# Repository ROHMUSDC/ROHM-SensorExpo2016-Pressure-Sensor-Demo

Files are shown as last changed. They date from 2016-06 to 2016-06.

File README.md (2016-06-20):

# ROHM Balloon Game Demo Public Repository
* Applicable Part Number Used: BM1383AGLV
* Applicable Part Number Demo/Development: SENSORSHLD1-EVK-101
* Description:  This Repo Containg Code, HW design files, and Explaination of how to run the balloon game demo featured at Sensors Expo 2016
* Website link:  TO BE ADDED
* Developer: USDC Applications Engineering Team, ROHM Semiconductor
* Date Started: JUNE 2016
* Related Projects: https://github.com/ROHMUSDC/ROHMSensorPlatformEVK , http://www.rohm.com/web/global/multi-sensor-shield

----
### Repository Contents
* "Documentation" Folder
  * "Sensor Shield General Datasheet" Folder - Contains the General Datasheet for this Shield Board
  * "Sensor Datasheets" Folder - Contains Datasheets for sensors on the Shield Board
* "HW Source Files" Folder 
  * "SENSORSHLD0-EVK-101 HW Design Files" Folder - Contains Schematic, BOM, Layout, Gerber Files for this revision of the Shield Board
  * "SENSORSHLD1-EVK-101 HW Design Files" Folder - Contains Schematic, BOM, Layout, Gerber Files for this revision of the shield Board
* "Platform Code" Folder
  * "Arduino_UNO_FirmwareExample" Folder - Provides documentation and example code for Arduino UNO Platform
  * "LAPIS_SensorPlatform_Firmware" Folder - Provides example code for ROHM's Sensor Platform Kit
  * "MultiTech_Dragonfly_FirmwareExample" Folder - Provides documentation and example code for MultiTech's Dragonfly
  * "Nordic_nRF51-DK_FirmwareExample" Folder - Provides documentation and example code for Nordic nRF51-DK
  * "NXP_LPCXpresso54102_BlinkyExample" Folder - Provides example code for NXP's LPCXpresso54102

----
### Current Supported Platforms
* Arduino UNO, Firmware Example and Documentation (This is our recommended starting point)
* LPCXpresso54102, Firmware Example Only
* Nordic Semiconductor nRF51-DK, Firmware Example and Documentation 
	*  Recommended for BTLE Low Power Sensor Applications
    *  MBED Repository Page: https://developer.mbed.org/teams/ROHMUSDC/code/Nordic_UART_TEMPLATE_ROHM/
* ROHM Sensor Platform Kit: Firmware Example  Only
	*  ROHM Sensor Platform Repository: https://github.com/ROHMUSDC/ROHMSensorPlatformEVK
* MultiTech Dragonfly and MTUDK2, Firmware Example and Documentation
	*  Recommended for Cellular Network Compatibility Applications
    *  MBED Repository Page: https://developer.mbed.org/teams/ROHMUSDC/code/MultiTech_DragonFly_ROHMSensorShield_Sam/

----
### FAQ
* Question:
	* What is the difference between SENSORSHLD0-EVK-101 and SENSORSHLD1-EVK-101?
* Answer:
	* Removed Erroneous Jumpers
	* Removed J5 to J11 and adjusted routing for J1 to J4
	* Added ROHM BM1422GMV Magnetometer, 1.8V level shifter, and 1.8V LDO (for Magnetometer usage)
	* Changed pressure sensor from BM1383GLV to BM1383AGLV.  (No HW change, but new PN has new FW I2C register mapping)
	* PN Change from ML8511 to ML8511A (only chip labelling change)
	* Kionix Corner Accelerometer: one PN, KX123-1050, has been adjusted to the KX124-1050
	
* Question:
	* I see x2 KX122-1037 and x2 KX122-1048 Accelerometers on the board.  What is the difference between these two part numbers?
* Answer: 
	  * The difference between KX122-1037 and KX122-1048 is the I2C register address scheme to control all 4 accelerometers using a single I2C master.  
	  * The KX122-1037 has a 7-bit register address of 0x1E or 0x1F (0x1E if ADDR pin is tied to GND, and 0x1F is ADDR pin is tied to VDD)
	  * The KX122-1048 has a 7-bit register address of 0x1C or 0x1D (0x1C if ADDR pin is tied to GND, and 0x1D is ADDR pin is tied to VDD)
	  * All other accelerometer functionality is the same.  Please see the datasheet for both devices at the following page: http://www.kionix.com/product/KX122-1037

* Question:
	* I've programmed my Arduino Uno board with the sample code provided in this repository.  However, The I2C operation does not seem to work. Do you know what may be the cause?
* Answer:
	* On the Arduino Uno board, please note that the I2C pins connected to the top left header are actually routed to pins A4 and A5 on the bottom right connector.  
	* This conflicts with the UV Sensor ADC output already existing on the board.  
	* Thus, in order to re-route this on our board, we suggest the following rework:
		* To disconnect the nets, remove R27 and R32
		* For UV Sensor Operation, connect the top pad of R31 to the bottom pad of R27
	* Please see the documentation "ROHM_SENSORSHLD1-EVK-101_ArduinoUsageManual_2016-05-31.pdf" or "ROHM_SENSORSHLD1-EVK-101_PlatformGuide_Arduino_2016-05-31.pdf" for additional details of this rework.	

----
### DISCLAIMER
This Technical Data is protected under copyright laws.

ROHM hereby grants you a nonexclusive, nontransferable license to use this Technical Data 
as long as you abide by the terms and conditions of this DISCLAIMER. 

However, you are not authorized to sell, loan, rent, lease, redistribute or license this Technical Data, 
in whole or in part, or in modified form, to anyone.

You may modify this Technical Data to suit your specific applications, 
but the rights to derivative works and said modifications shall belong to ROHM. 

You may make copies of this Technical Data as necessary for internal use only within your company.

ROHM shall not be responsible for ensuring proper application on all computer systems.
This Technical Data is provided AS IS. ROHM makes no guarantees, either implicitly or explicitly, 
regarding its usability, functionality, accuracy, merchantability, or fitness for a specific purpose.

In addition, you shall take full responsibility for the use of any information acquired from this Technical Data. 

ROHM does not assume warranty of any kind arising from the use of this Technical Data. ACCORDINGLY, 
IN NO EVENT SHALL ROHM BE RESPONSIBLE, WHETHER THROUGH CONTRACT OR TORT LIABILITY, 
FOR ANY DAMAGES (INCLUDING BUT NOT LIMITED TO LOST PROFITS OR OTHER INCIDENTAL, CONSEQUENTAL, 
OR PUNITIVE DAMAGES) ARISING OUT OF OR IN CONNECTION WITH THE USE OR APPLICATION OF THIS Technical Data.

Furthermore, this Technical Data is subject to change without notice.

Unless otherwise expressly provided herein, ROHM does not convey any license under patent rights 
or any other intellectual property rights (including those of third parties).

ROHM is not obligated to provide maintenance or support for the Technical Data.

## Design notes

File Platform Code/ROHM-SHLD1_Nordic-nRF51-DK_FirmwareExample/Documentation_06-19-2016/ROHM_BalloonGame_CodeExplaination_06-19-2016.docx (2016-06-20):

# Connecting the ROHM Sensor Shield to the Nordic nRF51-DK

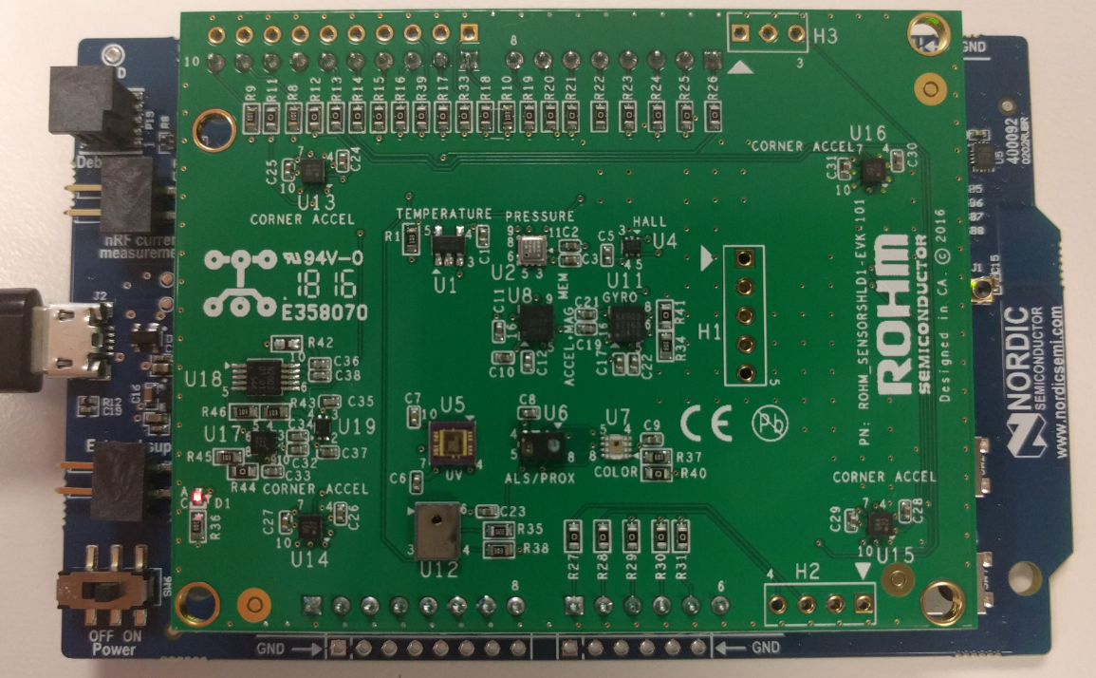
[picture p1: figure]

Above: ROHM SENSORSHLD1-EVK-101 directly connected to the Nordic nRF51-DK Platform

08 June 2016, Revision A

# Copyright and License

[Need to add Nordic References Here]

Please note that all references to ROHM’s Multi-Sensor Shield are also shared under open source guidelines under the GNU General Public License, Version 3. Details can be found at the following link: https://github.com/ROHMUSDC/ROHM_SensorPlatform_Multi-Sensor-Shield.

# Revision History

Date | Description | Revision ID
11 September 2015 | First Draft | A
25 November 2015 | Added Additional Sensor Information | A

# Introduction

The following document was written to provide a brief connection guide and starting point for using ROHM’s Multi-sensor shield with the Nordic nRF51-DK. This guide assumes that the user has basic functional knowledge of both the ROHM Multi-Sensor Shield and the Nordic Platform itself. If this is not correct, please see the following links for other guides and information on these products.

ROHM’s Multi-Sensor Shield GitHub Repository Page: https://github.com/ROHMUSDC/ROHM_SensorPlatform_Multi-Sensor-Shield

Nordic NRF51-DK MBED Platform Page: https://developer.mbed.org/platforms/Nordic-nRF51-DK/

Please note that the Nordic NRF51-DK Platform is a microcontroller platform; thus, this document will explain and show examples of how to connect to and convert values for the ROHM Sensor Kit Sensors. This includes explanations on the following sensors:

- ROHM BDE0600G – Analog Temperature Sensor
- LAPIS ML8511 – Analog UV Sensor
- ROHM BU52011HFV – Hall Switch Sensor
- KIONIX KMX62 – Digital Accelerometer and Magnetometer
- ROHM BM1383AGLV – Digital Barometric Pressure Sensor
- ROHM RPR-0521 – Digital Ambient Light Sensor and Proximity Sensor
- ROHM BH1745 – Digital Color Sensor
- KIONIX KX122 – Digital Accelerometer
- KIONIX KXG03 – Digital Gyroscopic Sensor
- ROHM BM1422 – MI Magnetometer Sensor

# Code Differences between ROHM SHLD0 and SHLD1

- Pressure Sensor is different on this board and uses an updated register map. See the Pressure sensor datasheet for more details (Temperature and pressure output are switched in I2C register map)
- Added section for newly added BM1422 Magnetometer Sensor IC
- Gyro Device I2C address changed due to conflict with other sensors. 7bit address was 0x4F and is not 0x4E (ADDR tied to GND on EVK board)

# Getting Started

1. Initial Setup
  a. ROHM Multi-Sensor Shield Board
    i. For this guide we will connect ROHM’s Multi-Sensor Shield board directly to the Nordic Platform using the standard Arduino Shield Headers
  b. The following are recommended for using the Nordic Platform for this guide
    i. PC
    ii. MBED account for online compiler access
    iii. USB Cable to power and program
    iv. Import the example code from the following repository on the MBED site into your online MBED complier
      1. https://developer.mbed.org/teams/ROHMUSDC/code/Nordic_UART_TEMPLATE_ROHM_SHLD1Update/

# Connecting ROHM Multi-Sensor Shield to the Nordic NRF51-DK Platform

## Hardware Connection for ROHM BDE0600G Temp Sensor to the Nordic Platform

- ROHM BDE0600G – Analog Temperature Sensor

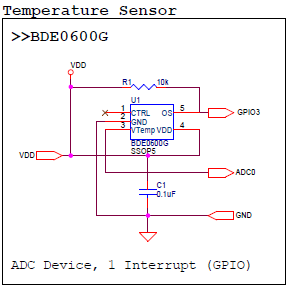
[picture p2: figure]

- As seen in the schematic above, this device connects 4 pins.
  - VDD – Connect to Nordic 3.3V output pin on power connector
  - GND – Connect to Nordic GND pin on the power connector
  - ADC0 – ADC Output for Temperature Readings, Connected to pin P0.03 on Nordic Board
  - GPIO3 – This pin is used to trigger the thermostat output function. This pin is not used in the example application.

## Software Explanation for ROHM BDE0600G Temp Sensor to the Nordic Platform

- Code Segments pertaining to this sensor can be found by defining and seeing code within the “AnalogTemp” #ifDef statements
- Pseudo-Code Explanation
  - Define Relevant Variables
  - Begin Loop()
    1. Read back the Analog Sensor Output from Pin P0.03
      - Note: Default Nordic Reference voltage is 5V; however we are supplying 3.3V to the sensor. Take these values into account when performing your conversions!
    2. Convert value to V, then to Temperature reading
      - Known Values
        - Temperature Sensitivity = -10.68mV/degC
        - Temperature Sensitivity = -0.01068V/degC
        - Temp Known Point = 1.753V @ 30 degC
      - Calculation
        - ADC_Voltage = (sensorValue / 1024) * 2.9V
        - ADC_Voltage = sensorValue * (2.9V/1024)
        - ADC_Voltage = sensorValue * 0.00283
        - Temperature (in deg C) = (ADC_Voltage - 1.753)/(-0.01068) + 30
    3. Format Serial Output and Return Information

## Hardware Connection for LAPIS ML8511 UV Sensor to the Nordic Platform

- LAPIS ML8511 – Analog UV Sensor

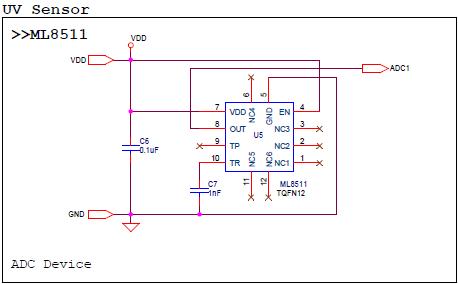
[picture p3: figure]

- As seen in the schematic above, this device connects 3 pins.
  - VDD – Connect to Nordic 3.3V output pin on power connector
  - GND – Connect to Nordic GND pin on the power connector
  - ADC1 – ADC Output for UV Sensor Output, Connected to pin P0.05 on Nordic Board

Software Explanation for LAPIS ML8511 UV Sensor to the Arduino Uno

- Code Segments pertaining to this sensor can be found by defining and seeing code within the “AnalogUV” #ifDef statements
- Pseudo-Code Explanation
  - Define Relevant Variables
  - Begin Loop()
    4. Read back the Analog Sensor Output from Pin P0.05
      - Note: Default Nordic Reference voltage is 5V; however we are supplying 3.3V to the sensor. Take these values into account when performing your conversions!
    5. Convert value to V, then to UV Intensity
      - Known Values
        - UV Sensitivity = 0.129 V/(mW/cm²)
        - Temp Known Point = 2.2V @ 10mW/cm²
      - Calculation
        - ADC_Voltage = (sensorValue / 1024) * 2.9V
        - ADC_Voltage = sensorValue * (2.9V/1024)
        - ADC_Voltage = sensorValue * 0.0029
        - UV Intensity (in mW/cm²)= (ADC_Voltage - 2.2)/(0.129) + 10
    6. Format Serial Output and Return Information

## Hardware Connection for ROHM BU52014 Hall Sensor to the Nordic Platform

- ROHM BU52011HFV – Hall Switch Sensor

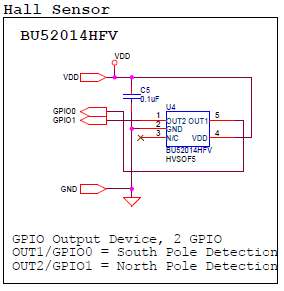
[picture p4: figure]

- As seen in the schematic above, this device connects 4 pins.
  - VDD – Connect to Nordic 3.3V output pin on power connector
  - GND – Connect to Nordic GND pin on the power connector
  - GPIO0, GPIO1 – Indicates Hall Switch Output
    - GPIO0: Indicates South Pole Detection
    - GPIO1: Indicates North Pole Detection

## Software Explanation for ROHM BU52014 Hall Sensor to the Nordic Platform

- Code Segments pertaining to this sensor can be found by defining and seeing code within the “HallSensor” #ifDef statements
- Pseudo-Code Explanation
  - Define Relevant Variables
  - Begin setup()
    7. Setup Nordic Pins P0.14 and P0.15 and Input pins
  - Begin loop()
    8. Perform digital reads on pins P0.14 and P0.15
      - Output will be either 1 or 0 and will indicate presence of north or south magnetic fields
    9. Format Serial Output and Return Information

## Hardware Connection for Kionix KMX62 Accel+Mag Sensor to the Nordic Platform

- Kionix KMX62 – Digital Accelerometer and Magnetometer

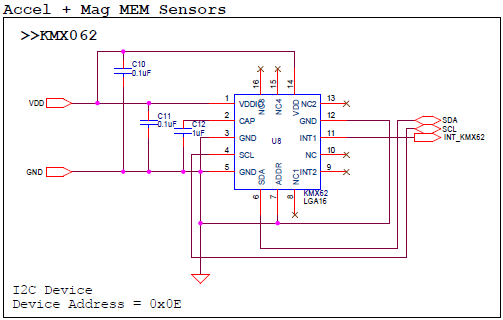
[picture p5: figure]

- As seen in the schematic above, this device connects 6 pins.
  - VDD – Connect to Nordic 3.3V output pin on power connector
  - GND – Connect to Nordic GND pin on the power connector
  - SDA/SCL – I2C Connection, connected to pin P0.30 and P0.07
  - INT_KMX62 - This pin is used monitor the interrupt pins on the KMX61. This pin is not used in the example application.

## Software Explanation for Kionix KMX62 Accel+Mag Sensor to the Nordic Platform

- Code Segments pertaining to this sensor can be found by defining and seeing code within the “KMX62” #ifDef statements
- Pseudo-Code Explanation
  - Define Relevant Variables
  - Begin Main()
    10. Set Baud Rate for Serial Output via Nordic BT Protocols
    11. Initialize Board Level LEDs
    12. Setup Interrupt Callback for “Periodic Callback”
    13. Setup PB for SW4
    14. Configure the Accel/Mag Sensor once by performing the following writes
      - 1. CNTL2 Register (0x3A), write 0x5F (4g Sensor Resolution, Max RES, Enable Temp/Mag/Accel)
        - Note: Please see the KMX62 Datasheet for additional information on these registers
  - Begin loop()
    15. Read back the Accelerometer output by reading 6 Bytes starting from address 0x0A. [0][1]...[5]
    16. Format Each of the X, Y, and Z axis acceleration
      - Note: to save some time with conversions, please note that these outputs are meant to be unsigned 14bit values. Thus, to make it easier to convert we recommend the following…
        - Xout = (float)(([1]<<8) | ([0]))/4
        - Yout = (float)(([3]<<8) | ([2]))/4
        - Zout = (float)(([5]<<8) | ([4]]))/4
    17. Convert Returned Value to g
      - Axis_ValueInG = MEMS_Accel_axis / 2048
    18. Read back the Magnetometer output by reading 6 Bytes starting from address 0x10. [0][1]...[5]
    19. Format Each of the X, Y, and Z axis mag data
      - Note: to save some time with conversions, please note that these outputs are meant to be unsigned 14bit values. Thus, to make it easier to convert we recommend the following…
        - Xout = (float)(([1]<<8) | ([0]))/4
        - Yout = (float)(([3]<<8) | ([2]))/4
        - Zout = (float)(([5]<<8) | ([4]]))/4
    20. Convert Returned Value to uT
      - Axis_ValueInuT = MEMS_Mag_axis * 0.146
    21. Format Serial Output and Return Information

## Hardware Connection for ROHM BM1383GLV Barometric Pressure Sensor to the Nordic Platform

- ROHM BM1383GLV Barometric Pressure Sensor

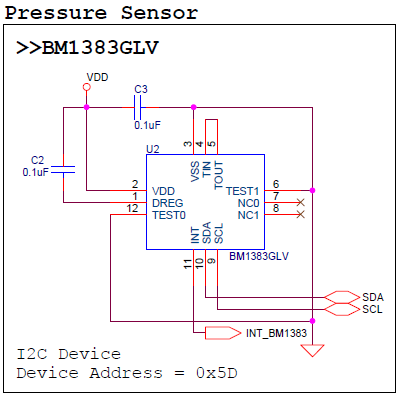
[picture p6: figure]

- As seen in the schematic above, this device connects 6 pins.
  - VDD – Connect to Nordic 3.3V output pin on power connector
  - GND – Connect to Nordic GND pin on the power connector
  - SDA/SCL – I2C Connection, connected to pin P0.30 and P0.07
  - INT_BM1383 - This pin is used monitor the interrupt pins on the BM1383. This pin is not used in the example application.

## Software Explanation for ROHM BM1383GLV Barometric Pressure Sensor to the Nordic Platform

- Code Segments pertaining to this sensor can be found by defining and seeing code within the “Pressure” #ifDef statements
- Pseudo-Code Explanation
  - Define Relevant Variables
  - Begin Main()
    22. Set Baud Rate for Serial Output via Nordic BT Protocols
    23. Initialize Board Level LEDs
    24. Setup Interrupt Callback for “Periodic Callback”
    25. Configure the Pressure Sensor once by performing the following writes:
      - 1. PWR_DOWN Register (0x12), write (0x01)
      - 2. SLEEP Register (0x13), write (0x01)
      - 3. Mode Control Register (0x14), write (0xC4)
      - Note: Please see the BM1383 datasheet for additional information on these registers
  - Begin loop()
    26. Read back the pressure and temperature output by reading 5 Bytes starting from address 0x1A. [0][1]...[4]
    27. Format raw temperature and pressure
      - Raw ADC Pressure (Integer Portion) = ([0]<<3) | ([1]>>5)
      - Raw ADC Pressure (Decimal Portion) = (([1] & 0x1f) << 6 | (([2] >> 2)));
      - Raw ADC Temp = ([3]<<8) | ([4])
    28. Convert Returned Raw Value to Real Values
      - Temp in C = Raw ADC Temp / 32
      - Pressure in hPa =
        - (Raw ADC Pressure(int)) + (Raw ADC Pressure(dec)*2⁻¹¹)
    29. Format Serial Output and Return Information

## Hardware Connection for ROHM RPR-0521 3-in-1 Ambient Light Sensor, Proximity Sensor, and IR LED Combo Package for the Nordic Platform

- ROHM RPR-0521 ALS/PROX Sensor

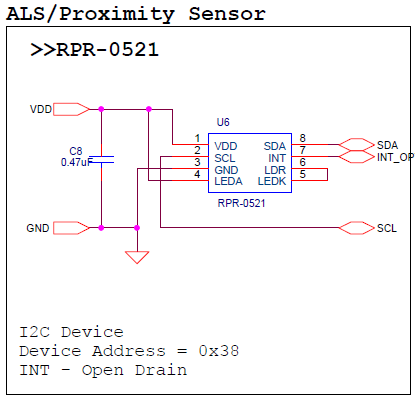
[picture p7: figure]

- As seen in the schematic above, this device connects 6 pins.
  - VDD – Connect to Nordic 3.3V output pin on power connector
  - GND – Connect to Nordic GND pin on the power connector
  - SDA/SCL – I2C Connection, connected to pin P0.30 and P0.07
  - INT_Optical - This pin is used monitor the interrupt pins on the RPR-0521. This pin is not used in the example application.

## Software Explanation for ROHM RPR-0521 3-in-1 Ambient Light Sensor, Proximity Sensor, and IR LED Combo Package to the Nordic Platform

- Code Segments pertaining to this sensor can be found by defining and seeing code within the “RPR0521” #ifDef statements
- Pseudo-Code Explanation
  - Define Relevant Variables
  - Begin Main()
    30. Set Baud Rate for Serial Output via Nordic BT Protocols
    31. Initialize Board Level LEDs
    32. Setup Interrupt Callback for “Periodic Callback”
    33. Configure the Ambient Light Sensor and Proximity Sensor once by performing the following writes:
      - 1. Mode Control Register (0x41), write (0xC6)
      - 2. ALS_PS_Control Register (0x42), write (0x03)
      - 3. Persist Register (0x43), write (0x20)
      - Note: Please see the RPR-0521 datasheet for additional information on these registers
  - Begin loop()
    34. Read back the ALS output by reading 6 Bytes starting from address 0x44. [0][1]...[5]
    35. Format Raw ambient light and proximity
      - RAW PROX ADC = ([1]<<8) | ([0])
      - RAW ALS DATA0 = ([3]<<8) | ([2])
      - RAW ALS DATA1 = ([5]<<8) | ([4])
    36. Convert Raw Returned Value to Real Values
      - ALS can be returned by using the following code block to return ALS value in lx (RPR0521_ALS_OUT)
    37. Format Serial Output and Return Information

## Hardware Connection for ROHM BH1745NUC Color Sensor for the Nordic Platform

- ROHM BH1745NUC Color Sensor

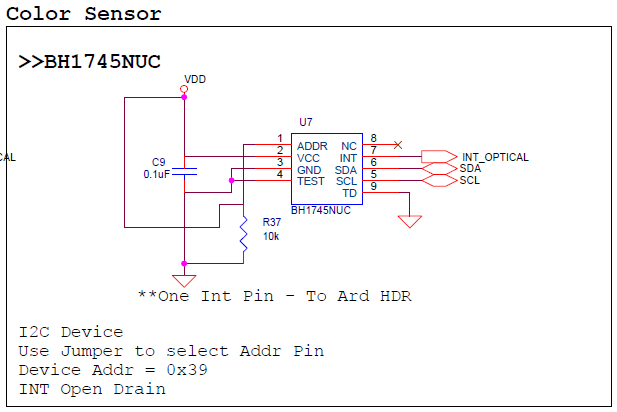
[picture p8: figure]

- As seen in the schematic above, this device connects 6 pins.
  - VDD – Connect to Nordic 3.3V output pin on power connector
  - GND – Connect to Nordic GND pin on the power connector
  - SDA/SCL – I2C Connection, connected to pin P0.30 and P0.07
  - INT_Optical - This pin is used monitor the interrupt pins on the RPR-0521. This pin is not used in the example application.

## Software Explanation for ROHM BH1745NUC Color Sensor to the Nordic Platform

- Code Segments pertaining to this sensor can be found by defining and seeing code within the “Color” #ifDef statements
- Pseudo-Code Explanation
  - Define Relevant Variables
  - Begin Main()
    38. Set Baud Rate for Serial Output via Nordic BT Protocols
    39. Initialize Board Level LEDs
    40. Setup Interrupt Callback for “Periodic Callback”
    41. Configure the Color Sensor once by performing the following writes:
      - 1. Persistence Register (0x61), write (0x03)
      - 2. Mode Control 1 Register (0x41), write (0x00)
      - 3. Mode Control 2 Register (0x42), write (0x92)
      - 4. Mode Control 3 Register (0x43), write (0x02)
      - Note: Please see the color sensor datasheet for additional information on these registers
  - Begin loop()
    42. Read back the color output by reading 6 Bytes starting from address 0x50. [0][1]...[5]
    43. Format Raw color
      - RED ADC = ([1]<<8) | ([0])
      - GREEN ADC = ([3]<<8) | ([2])
      - BLUE ADC = ([5]<<8) | ([4])
    44. Convert Raw Returned Value to Real Values
      - Coming Soon!
    45. Format Serial Output and Return Information

## Hardware Connection for Kionix KX122 Accelerometer Sensor for the Nordic Platform

- Kionix KX122 Accelerometer Sensor

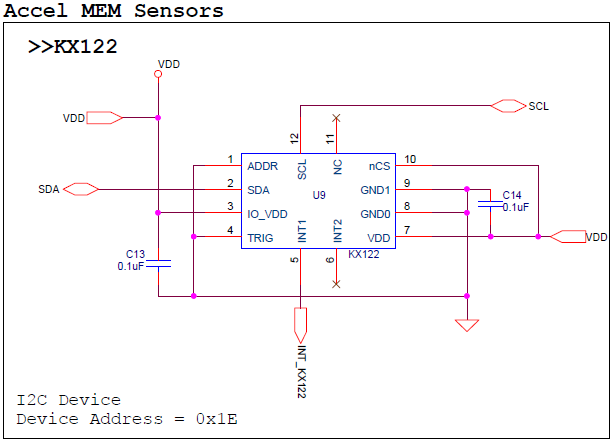
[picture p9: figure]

- As seen in the schematic above, this device connects 6 pins.
  - VDD – Connect to Nordic 3.3V output pin on power connector
  - GND – Connect to Nordic GND pin on the power connector
  - SDA/SCL – I2C Connection, connected to pin P0.30 and P0.07
  - INT_KX122 - This pin is used monitor the interrupt pins on the KX122. This pin is not used in the example application.

## Software Explanation for Kionix KX122 Accelerometer Sensor to the Nordic Platform

- Code Segments pertaining to this sensor can be found by defining and seeing code within the “KX122” #ifDef statements
- Pseudo-Code Explanation
  - Define Relevant Variables
  - Begin Main()
    46. Set Baud Rate for Serial Output via Nordic BT Protocols
    47. Initialize Board Level LEDs
    48. Setup Interrupt Callback for “Periodic Callback”
    49. Configure the Accelerometer Sensor once by performing the following writes:
      - 1. CNTL1 Register (0x18), write (0x41)
      - 2. ODCNTL Register (0x1B), write (0x02)
      - 3. CNTL3 Register (0x1A), write (0xD8)
      - 4. TILT_TIMER Register (0x22), write (0x01)
      - 5. CNTL1 Register (0x18), write (0xC1) (Enable bit to ON)
      - Note: Please see the KX122 datasheet for additional information on these registers
  - Begin loop()
    50. Read back the Accelerometer output by reading 6 Bytes starting from address 0x06. [0][1]...[5]
    51. Format Raw accelerometer
      - ACCEL X Axis Raw = ([1]<<8) | ([0])
      - ACCEL Y Axis Raw = ([3]<<8) | ([2])
      - ACCEL Z Axis Raw = ([5]<<8) | ([4])
    52. Convert Raw Returned Value to g
      - ACCEL X in g = ACCEL X Axis Raw / 16384
      - ACCEL X in g = ACCEL Y Axis Raw / 16384
      - ACCEL X in g = ACCEL Z Axis Raw / 16384
    53. Format Serial Output and Return Information

## Hardware Connection for Kionix KXG03 Gyroscopic Sensor for the Nordic Platform

- Kionix KXG03 Gyroscopic Sensor

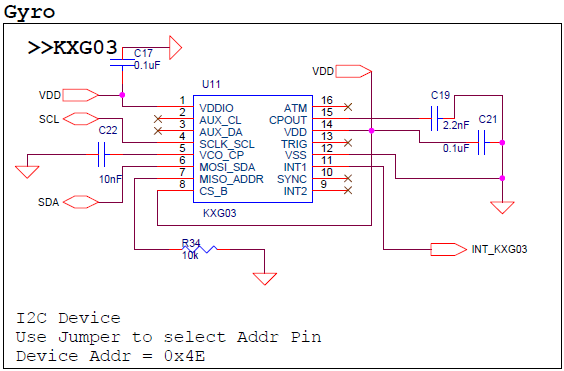
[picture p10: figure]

- As seen in the schematic above, this device connects 6 pins.
  - VDD – Connect to Nordic 3.3V output pin on power connector
  - GND – Connect to Nordic GND pin on the power connector
  - SDA/SCL – I2C Connection, connected to pin P0.30 and P0.07
  - INT_KXG03 - This pin is used monitor the interrupt pins on the KXG03. This pin is not used in the example application.

## Software Explanation for Kionix KXG03 Gyroscopic Sensor to the Nordic Platform

- Code Segments pertaining to this sensor can be found by defining and seeing code within the “KXG03” #ifDef statements
- Pseudo-Code Explanation
  - Define Relevant Variables
  - Begin Main()
    54. Set Baud Rate for Serial Output via Nordic BT Protocols
    55. Initialize Board Level LEDs
    56. Setup Interrupt Callback for “Periodic Callback”
    57. Configure the Gyroscopic Sensor once by performing the following writes:
      - STDBY Register (0x43), write 0x00.
      - Note: Please see the KXG03 datasheet for additional information on these registers
  - Begin loop()
    58. Read back the Gyroscopic output by reading 6 Bytes starting from address [0x02]. [0][1]...[5]
    59. Format Raw Gyro data
      - Gyro_X_RawOUT = ([1]<<8) | ([0])
      - Gyro_Y_RawOUT = ([3]<<8) | ([2])
      - Gyro_Z_RawOUT = ([5]<<8) | ([4])
    60. Cancel for offset value
- Measure RawOUT data 10 times in order to proofread offset value.
- Calculate average offset value. This data is defined as proofread data.
- Subtract proofread data from each RawOUT data.
    61. Convert Raw Returned Value to deg/sec
      - Gyro_ X = (float)KXG03_Gyro_X_RawOUT2 * 0.007813 + 0.000004
      - Gyro_ Y = (float)KXG03_Gyro_Y_RawOUT2 * 0.007813 + 0.000004
      - Gyro_Z = (float)KXG03_Gyro_Z_RawOUT2 * 0.007813 + 0.000004
    62. Format Serial Output and Return Information

## Hardware Connection for ROHM BM1422 Magnetometer Sensor for the Arduino Uno

- ROHM BM1422Magnetometer Sensor

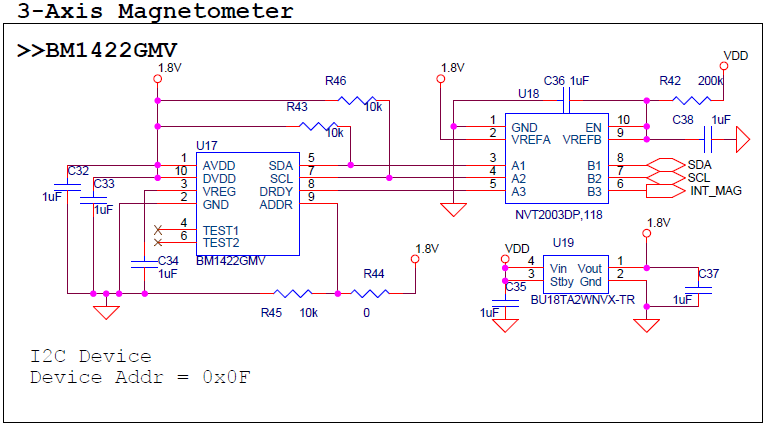
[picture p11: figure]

- As seen in the schematic above, this device is slightly more complicated than the other devices on this shield.
  - Part Explanation:
    - U17 = BM1422GMV Magnetometer
      - 1.8V max input voltage… therefore, we can’t use the 3.3V rail native to the system. U18 and U19 are added to protect the magnetometer from the 3.3V system voltage.
    - U18 = NVT2003DP Level Shifter for I2C and Interrupt lines
      - Used to reduce I2C interface and interrupt pin connection’s 3.3V signals from the Arduino board to 1.8V to the sensor.
    - U19 = BU18TA2WNVX LDO Regulator
      - Used to source power to the magnetometer and the 1.8V logic level side of the level shifter U18
- When looking at this system together, we can see than ultimately, there are 5 connections
  - VDD – Connect to Arduino 3.3V output pin on power connector
  - GND – Connect to Arduino GND pin on the power connector
  - SDA/SCL – I2C Connection, connected to A4 and A5
  - INT_MAG - This pin is used monitor the interrupt pins on the BM1422GMV. This pin is not used in the example application.

## Software Explanation for ROHM BM1422 Magnetometer Sensor to the Arduino Uno

- Code Segments pertaining to this sensor can be found by defining and seeing code within the “Magnetometer” #ifDef statements
- Pseudo-Code Explanation
  - Define Relevant Variables
  - Begin Main()
    63. Set Baud Rate for Serial Output via Nordic BT Protocols
    64. Initialize Board Level LEDs
    65. Setup Interrupt Callback for “Periodic Callback”
    66. Configure the Magnetometer Sensor once by performing the following writes:
      - 1. CNTL1 Register (0x1B), write 0xC0
      - 2. CNTL4 Register (0x5C), write 0x00
      - 3. CNTL4 Register (0x5D), write 0x00
      - 4. CNTL3 Register (0x1D), write 0x40
      - Note: Please see the BM1422GMV datasheet for additional information on these registers
  - Begin loop()
    67. Read back the Magnetometer Sensor output by reading 6 Bytes starting from address 0x10. [0][1]...[5]
    68. Format Raw Magnetometer data
      - Mag_X_RawOUT = ([1]<<8) | ([0])
      - Mag_Y_RawOUT = ([3]<<8) | ([2])
      - Mag_Z_RawOUT = ([5]<<8) | ([4])
    69. Format Serial Output and Return Information

Connecting ROHM’s Sensor Shield to Nordic nRF51-DK SENSORSHLD1-EVK-101 08 June, 2016 – Revision A

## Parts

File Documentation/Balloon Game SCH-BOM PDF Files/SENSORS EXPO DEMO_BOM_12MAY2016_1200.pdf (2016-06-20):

Sensors Expo Demo
Revision: 0.01

Bill Of Materials

Item | Quantity | Reference | Part | PCB Footprint | DESCRIPTION | MFG1 | MFG1_PART# | DISTR1 | DISTR1_PART# | Note
1 | 1 | B2 | Li-Ion | 100mil_VIA-2 | | | | | | DNP
2 | 1 | C97 | 1.0pF | C0402 | CAP CER 1PF 50V NP0 0402 | Samsung | CL05C010CB5NNNC | Digi-Key | 1276-1595-1-ND
3 | 1 | C99 | 1.2pF | C0402 | CAP CER 1.2PF 50V .25PF 0402 | Murata | GRM1555C1H1R2CA01D | Digi-Key | 490-5927-1-ND
4 | 1 | C98 | 1.5pF | C0402 | CAP CER 1.5PF 50V NP0 0402 | Murata | GRM1555C1H1R5CA01D | Digi-Key | 490-5891-1-ND
5 | 1 | C96 | 3.9pF | C0402 | CAP CER 3.9PF 50V NP0 0402 | Murata | GRM1555C1H3R9CA01D | Digi-Key | 490-5940-1-ND
6 | 4 | C86,C87,C90,C9112pF | | C0402 | CAP CER 12PF 50V NP0 0402 | Samsung | CL05C120JB5NNNC | Digi-Key | 1276-1178-1-ND
7 | 2 | C102,C119 | 120pF | C0402 | CAP CER 120PF 10V X7R 01005 | Murata | GRM022R71A121KA01L | Digi-Key | 490-8617-1-ND
8 | 1 | C93 | 1.0nF | C0402 | CAP CER 1000PF 50V X7R 0402 | Murata | GRM155R71H102KA01D | Digi-Key | 490-1303-1-ND
9 | 2 | C94,C127 | 2.2nF | C0402 | CAP CER 2200PF 50V 10% X5R 0402 | Murata | GRM155R61H222KA01D | Digi-Key | 490-8257-1-ND
10 | 2 | C105,C121 | 2200pF | C0402 | CAP CER 2200PF 16V 10% X5R 0402 | Murata | GRM155R61C222KA01D | Digi-Key | 490-6311-1-ND
11 | 1 | C129 | 10nF | C0402 | CAP CER 10000PF 16V 10% X5R 0402 | Murata | GRM155R61C103KA01D | Digi-Key | 490-6309-1-ND
12 | 1 | C95 | 47nF | C0402 | CAP CER 0.047UF 16V X7R 0402 | Kemet | C0402C473K4RACTU | Digi-Key | 399-3519-1-ND
13 | 12 | C88,C89,C92,C103,C104,C108,C109,C111,C128,C130,C131,C132 0.1uF | | C0402 | CAP CER 0.1UF 16V X5R 0402 | Murata | GRM155R61C104KA88D | Digi-Key | 490-5415-1-ND
14 | 1 | C125 | 0.33uF | C0402 | CAP CER 0.33UF 10V X5R 0402 | Murata | GRM155R61A334KE15D | Digi-Key | 490-3263-1-ND
15 | 11 | C106,C110,C112,C113,C114,C115,C117,C120,C124,C126,C133 1uF | | C0402 | CAP CER 1UF 16V X5R 0402 | Murata | GRM155R61C105KE01D | Digi-Key | 490-10453-1-ND
16 | 1 | C122 | 2.2uF | C0402 | CAP CER 2.2UF 16V X5R 0402 | Murata | GRM155R61C225KE11D | Digi-Key | 490-10695-1-ND
17 | 3 | C82,C83,C85 | 4.7uF | C0402 | CAP CER 4.7UF 6.3V X5R 0402 | Murata | GRM155R60J475ME47D | Digi-Key | 490-5915-1-ND
18 | 4 | C101,C107,C116,C118 10uF | | C1206 | CAP CER 10UF 10V X5R 1206 | Murata | GRM31CR61A106KA01L | Digi-Key | 490-1820-1-ND
19 | 1 | C84 | 100uF | C1206 | CAP CER 100UF 6.3V X5R 1206 | Taiyo Yuden | JMK316ABJ107ML-T | Digi-Key | 587-3395-1-ND
20 | 1 | C100 | DNP | C0402 | | | | | | DNP
21 | 1 | C123 | DNP | C0402 | CAP CER 2.2UF 16V X5R 0402 | Murata | GRM155R61C225KE11D | Digi-Key | 490-10695-1-ND | DNP
22 | 2 | D3,D4 | LED | D0402 | LED GREEN CLEAR 0402 SMD | Rohm | SML-P11MTT86 | Digi-Key | 511-1652-2-ND
23 | 1 | J10 | 1x8 HEADER | HDR_1X8_100 | CONN HEADER 8 POS 2.54 | Würth Elektronik | 61300811121 | Digi-Key | 732-5321-ND
24 | 1 | L12 | 3.3nH | L0402 | FIXED IND 3.3NH 550MA 160 MOHM | Taiyo Yuden | HK10053N3S-T | Digi-Key | 587-1507-1-ND
25 | 1 | L10 | 4.7nH | L0402 | FIXED IND 4.7NH 300MA 240 MOHM | Johanson | L-07C4N7SV6T | Digi-Key | 712-1417-1-ND
26 | 1 | L9 | 15nH | L0603 | FIXED IND 15NH 300MA 450 MOHM | Johanson | L-14C15NJV4T | Digi-Key | 712-1436-1-ND
27 | 1 | L11 | 27nH | L0402 | FIXED IND 27NH 300MA 460 MOHM | Murata | LQG15HS27NJ02D | Digi-Key | 490-2628-1-ND
28 | 1 | L13 | 4.7uH | INDM3838X165 | FIXED IND 4.7UH 1.2A 105 MOHM | Würth Elektronik | 744031004 | Digi-Key | 732-1008-1-ND
29 | 1 | L14 | 4.7uH | INDM3735X180 | Ind Power Shielded 4.7uH 20% 100KHz Ferrite 2A T/R | Murata | 1231AS-H-4R7M=P3 | Mouser | 81-1231AS-H-4R7MP3
30 | 1 | L8 | 10uH | L0805 | FIXED IND 10UH 150MA 360 MOHM | Taiyo Yuden | LBR2012T100K | Digi-Key | 587-2045-1-ND
31 | 2 | TEST1_N,P23 | TP_TH_63MIL_RED | TP_TH | TEST POINT PC MULTI PURPOSE RED | Keystone Electronics | 5010 | DIGIKEY | 5010K-ND
32 | 3 | Q4,Q5,Q6 | RE1C002UNTCL | EMT3 | MOSFET N-CH 20V 0.2A EMT3 | Rohm | RE1C002UNTCL | Digi-Key | RE1C002UNTCLCT-ND
33 | 8 | Q7,Q8,Q9,Q10,Q11,Q12,Q13,Q14 EM6K1T2R | | ROHM_EM6K1_SOT-416 | MOSFET 2N-CH 30V .1A EMT6 | Rohm | EM6K1T2R | Digi-Key | EM6K1T2RCT-ND
34 | 4 | R77,R89,R143,R152 0 | | R0402 | RES SMD 0.0OHM JUMPER 1/16W 0402 | Rohm | MCR01MRTJ000 | Digi-Key | RHM0.0CECT-ND
35 | 15 | R100,R103,R106,R109,R112,R115,R118,R121,R124,R127,R130,R133,R136,R139,R142 22 | | R0402 | RES SMD 22 OHM 5% 1/16W 0402 | Rohm | MCR01MRTJ220 | Digi-Key | RHM22CECT-ND
36 | 15 | R99,R102,R105,R108,R111,R114,R117,R120,R123,R126,R129,R132,R135,R138,R141 36 | | R0402 | RES SMD 36 OHM 5% 1/16W 0402 | Rohm | MCR01MRTJ360 | Digi-Key | RHM36CECT-ND
37 | 2 | R72,R74 | 43 | R0402 | RES SMD 43 OHM 5% 1/16W 0402 | Rohm | MCR01MRTJ430 | Digi-Key | RHM43CECT-ND
38 | 1 | R73 | 56 | R0402 | RES SMD 56 OHM 1% 1/16W 0402 | Rohm | TRR01MZPF56R0 | Digi-Key | RHM56BHCT-ND
39 | 15 | R98,R101,R104,R107,R110,R113,R116,R119,R122,R125,R128,R131,R134,R137,R140 180 | | R0402 | RES SMD 180 OHM 5% 1/16W 0402 | Rohm | MCR01MRTJ181 | Digi-Key | RHM180CECT-ND
40 | 2 | R91,R92 | 200 | R0402 | RES SMD 200 OHM 5% 1/16W 0402 | Rohm | MCR01MRTJ201 | Digi-Key | RHM200CEDKR-ND
41 | 1 | R145 | 430 | R0402 | RES SMD 430 OHM 5% 1/16W 0402 | Rohm | MCR01MRTJ431 | Digi-Key | RHM430CECT-ND
42 | 1 | R146 | 510 | R0402 | RES SMD 510 OHM 5% 1/16W 0402 | Rohm | MCR01MRTJ511 | Digi-Key | RHM510CECT-ND
43 | 1 | R149 | 1k | R0402 | RES SMD 1K OHM 5% 1/16W 0402 | Rohm | MCR01MRTJ102 | Digi-Key | RHM1.0KCECT-ND
44 | 1 | R90 | 2k | R0402 | RES SMD 2K OHM 1% 1/16W 0402 | Rohm | MCR01MRTF2001 | Digi-Key | RHM2KCDCT-ND
45 | 4 | R153,R154,R155,R156 2.2k | | R0402 | RES SMD 2.2K OHM 5% 1/16W 0402 | Rohm | MCR01MRTJ222 | Digi-Key | RHM2.2KCECT-ND
46 | 4 | R79,R87,R148,R150 4.7k | | R0402 | RES SMD 4.7K OHM 5% 1/16W 0402 | Rohm | MCR01MRTJ472 | Digi-Key | RHM4.7KCECT-ND
47 | 15 | R75,R76,R80,R81,R82,R83,R84,R85,R86,R93,R94,R95,R96,R97,R151 10k | | R0402 | RES SMD 10K OHM 5% 1/16W 0402 | Rohm | MCR01MRTJ103 | Digi-Key | RHM10KCEDKR-ND
48 | 2 | R88,R144 | 39k | R0402 | RES SMD 39K OHM 5% 1/16W 0402 | Rohm | MCR01MRTJ393 | Digi-Key | RHM39KCECT-ND
49 | 2 | R70,R71 | 51k | R0402 | RES SMD 51K OHM 1% 1/16W 0402 | Rohm | MCR01MRTF5102 | Digi-Key | RHM51KCDCT-ND
50 | 2 | R78,R147 | 56k | R0402 | RES SMD 56K OHM 5% 1/16W 0402 | Rohm | MCR01MRTJ563 | Digi-Key | RHM56KCECT-ND
51 | 22 | UART_TX1,UART_RX1,TP_SDA1,TP_SCL1,SPI_SCLK1,SPI_RST1,SPI_MOSI1,SPI_MISO1,SPI_CS1,TP20,TP21,TP22,TP23,TP24,TP25,TP26,TP27,TP28,TP29,TP30,TP31,TP32 T POINT R | TP_R | DNP. Not component
52 | 1 | SW1 | EVP-BB2A1B000 | SW_PANASONIC_EVPBB_53H | SWITCH TACTILE SPST-NO 0.02A 15V | Panasonic | EVP-BB2A1B000 | Digi-Key | P17066CT-ND
53 | 1 | U23 | USBmicroB | FCI_10118194-0001LF | CONN USB MICRO B RECPT SMT R/A | FCI | 10118194-0001LF | Digi-Key | 609-4618-1-ND
54 | 1 | U24 | nRF51422 | 48-VFQFN | IC SOC 2.4GHZ 256K FLASH 48QFN | Nordic Semiconductor | NRF51422-QFAA-R7 | Digi-Key | 1490-1030-1-ND
55 | 1 | U25 | ANT2012LL13R2400A | YAGEO_ANT2012 | PIFA CHIP ANTENNA 2.4GHZ | Yageo | ANT2012LL13R2400A | Digi-Key | 311-1534-1-ND
56 | 1 | U26 | SMLVN6RGB | ROHM_SMLVN6RGB1W1 | LED RGB DIFFUSED 6SMD | Rohm | SMLVN6RGB1W1 | Digi-Key | 846-1187-1-ND
57 | 2 | U27,U50 | BD8306MUV | VQFN016V3030 | IC REG BUCK BOOST ADJ 2A 16VQFN | Rohm | BD8306MUV-E2 | Digi-Key | BD8306MUV-E2CT-ND
58 | 2 | U28,U29 | BH1745 | WSON008X2120 | IC COLOR SENSOR DGTL 8WSON | Rohm | BH1745NUC-E2 | Digi-Key | BH1745NUC-E2CT-ND
59 | 1 | U30 | Left Servo | 100mil_Via3 | Custom Part DO NOT POPULATE | | | | | DNP
60 | 1 | U31 | Right Servo | 100mil_Via3 | Custom Part DO NOT POPULATE | | | | | DNP
61 | 1 | U32 | STBC08 | DFN6 | IC BATT CHRGR LI-ION 800MA DFN6 | STMicroelectronics | STBC08PMR | Digi-Key | 497-5808-1-ND
62 | 1 | U33 | BM1383 | CLGA12V025M | Pressure Sensor IC | Rohm | BM1383GLV | TBD | TBD
63 | 1 | U34 | KX122 | LGA12R50P_200X200X90 | ACCELEROMETER TRI-AXIS 12LGA | Kionix | KX122-1037 | Digi-Key | 1191-1041-1-ND
64 | 16 | U35,U36,U37,U38,U39,U40,U41,U42,U43,U44,U45,U46,U47,U48,U49,U51 SMLP34RGB2W | | ROHM_SMLP34 | LED RGB DIFFUSED 0404 SMD | Rohm | SMLP34RGB2W3 | Digi-Key | SMLP34RGB2W3CT-ND
65 | 1 | U52 | ML620Q504H | TQFP50P900X900X120-48 | IC MCU 16BIT 64KB FLASH 48TQFP | Rohm | ML620Q504H-NNNTBWABL | Digi-Key | ML620Q504H-NNNTBWABLCT-ND
66 | 1 | U53 | KXG03 | LGA16R50P_300X300X90 | TRI-AXIS GYROSCOPE/TRI-AXIS ACC | Kionix | KXG03-1034-FR | Digi-Key | 1191-1043-1-ND
67 | 1 | U54 | KX022 | LGA12S50P_200X200X90 | ACCELEROMETER TRI-AXIS 12LGA | Kionix | KX022-1020-FR | Digi-Key | 1191-1038-1-ND
68 | 1 | Y4 | 16MHz | NDK_NX2520SA | CRYSTAL 16.0000MHZ 8PF SMD | NDK | NX2520SA-16MHZ-STD-CSW-5 | Digi-Key | 644-1169-1-ND
69 | 1 | Y5 | 32.768kHz | EPSON_FC-135R | CRYSTAL 32.7680KHZ 6.0PF SMT | Epson | FC-135R 32.7680KA-E3 | Digi-Key | SER4074CT-ND
70 | 2 | J11,J13 | HDR_1X2_2P54MM | HDR_1X2_2P54MM | DNP. Not component
71 | 46 | TP48,TP49,TP50,TP51,TP52,TP53,TP54,TP55,TP56,TP57,TP58,TP59,TP60,TP61,TP62,TP63,TP64,TP65,TP66,TP67,TP68,TP69,TP70,TP71,TP72,TP73,TP74,TP75,TP76,TP77,TP78,TP79,TP80,TP81,TP82,TP83,TP84,TP85,TP86,TP87,TP88,TP89,TP90,TP91,TP92,TP93 TP_300X150 | TP_300X150 | DNP. Not component

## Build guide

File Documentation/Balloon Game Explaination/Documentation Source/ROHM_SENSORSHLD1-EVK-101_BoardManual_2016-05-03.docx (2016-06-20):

# Product Overview: SENSORSHLD1-EVK-101

# ROHM Sensor Shield

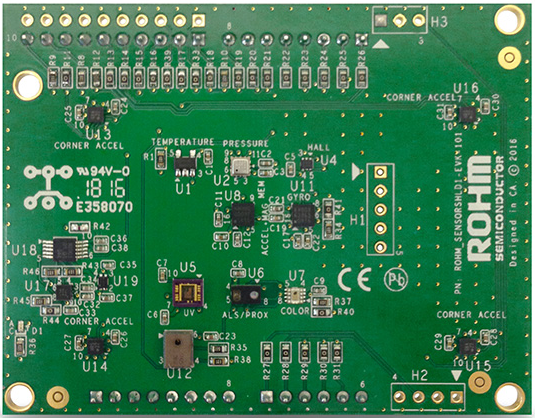
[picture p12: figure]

Above: Top view of ROHM SENSORSHLD1-EVK-101

03 May 2016, Revision A

# Introduction

The following document was written to provide a brief connection guide and general information about ROHM’s SENSORSHLD1-EVK-101. Supplementary information including application examples and HW design files for this board can be found at the following repository link.

ROHM’s Multi-Sensor Shield GitHub Repository Page: https://github.com/ROHMUSDC/ROHM_SensorPlatform_Multi-Sensor-Shield

ROHM’s SENSORSHLD1-EVK-101 is a shield evaluation board that connects all ROHM sensor products onto a single board. This shield uses standard Arduino shield interface pins; therefore, can connect to any evaluation kit that has a shield interface header. The shield contains the following sensors:

- Core Sensors:
  - ROHM BDE0600G – Analog Temperature Sensor
  - ROHM BM1383AGLV – Digital Barometric Pressure Sensor
  - ROHM BU52014HFV – Hall Switch Sensor (Omnipolar with Polarity Discrimination)
  - ROHM BM1422GMV – Magnetometer Sensor
  - KIONIX KX122 – Digital Accelerometer
  - KIONIX KMX62 – Digital Magnetometer and Accelerometer
  - KIONIX KXG03 – Digital Gyroscope and Accelerometer
  - LAPIS ML8511A – Analog UV Sensor
  - ROHM RPR-0521 – Digital Ambient Light Sensor and Proximity Sensor
  - ROHM BH1745 – Digital Color Sensor
- Special Functions:
  - KNOWLES SPM0423HD4H-WB – Digital Microphone
    - Primarily for use with NXP MCU Lineup
  - KIONIX KX122-1037, KX122-1048 – Accelerometer
    - For four corner Accelerometer algorithm development
    - Difference between 1037 and 1048 is the I2C register address scheme to control all 4 accelerometers using a single I2C master

# Key Differences between SHLD0 and SHLD1

- SENSORSHLD1-EVK-101 PN is the recommended evaluation board part number for new designs
- Removed Erroneous Jumpers
- Removed J5 to J11 and adjusted routing for J1 to J4
- Added ROHM BM1422GMV Magnetometer, 1.8V level shifter, and 1.8V LDO (for Magnetometer usage)
- Changed pressure sensor from BM1383GLV to BM1383AGLV. (No HW change, but new PN has new FW I2C register mapping)
- PN Change from ML8511 to ML8511A (only chip labelling change)
- KIONIX Accelerometers
  - Removed original KX022
  - Changed corner Accelerometers to KX022 variation (smaller)

# General Board Specifications

For the specifications of the individual sensors on this shield board, please refer to the associated datasheet/application note that can be found on www.rohm.com

In general, this shield board will be powered by the V3.3 pin (Pin 4 of Header H4) on the shield board. Please only connect a maximum of 3.3V to this pin as it is tied to the VDD of the full system and some of the sensors onboard cannot tolerate voltages greater than 3.3V.

# Hardware Explanation Section

1. POWER ON LED: When the shield have 3.3V connected to the VCC Net, this LED will turn on
2. BDE0600G Temperature Sensor
3. BM1383GLV Pressure Sensor
4. BU52014HFV Hall Effect Switch Sensor
5. BM1422GMV Magnetometer Sensor
6. KMX62 Accelerometer and Magnetometer Combo Sensor
7. KXG03 Gyroscope and Accelerometer Combo Sensor
8. ML8511/A UV Sensor
9. RPR-0521 Combo Ambient Light Sensor and Proximity Sensor
10. BH1745 RGB Color Sensor
11. H4 – Standard Power Header
  a. On the shield board, this header is only connected to pins 4, 7 and 8. See section below for an explanation of the shield connector’s pin out
12. H5 – Standard Analog In Header
  a. See section below for an explanation of the shield connector’s pinout
13. H7 – Standard Digital Header 1
  a. See section below for an explanation of the shield connector’s pinout
14. H10 - Auxiliary header for Microphone interface
15. H6 – Standard Arduino Digital Header 2
  a. See section below for an explanation of the shield connector’s pinout
16. 0 Ohm Jumper Line for pins connected to H5

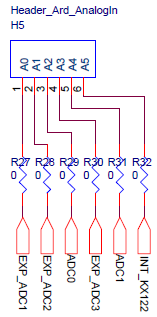
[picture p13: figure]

  b. The purpose of these resistor shorts are to depopulate pin connections on the shield if the user decides to use a pass through path or needs to adjust pin functionality depending on the needed pin configuration
17. 0 Ohm Jumper Line for pins connected to H6 and H7

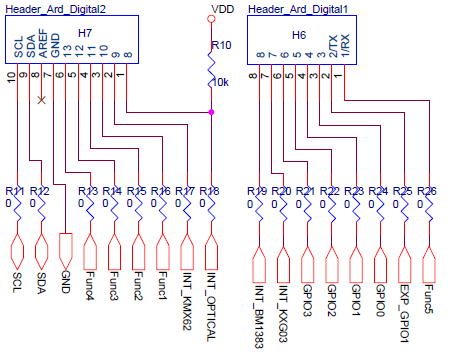
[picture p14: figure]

  b. The purpose of these resistor shorts are to depopulate pin connections on the shield if the user decides to use a pass through path or needs to adjust pin functionality depending on the needed pin configuration
18. H3 – Expansion Header for ROHM Breakout Boards/Generic Interface (3 Pin – ADC/GPIO x1)

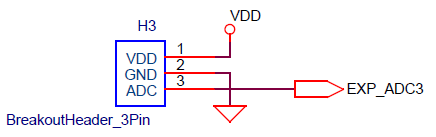
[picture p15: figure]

  b. This header is an expansion header to connect any additional ADC/GPIO x1 based sensors that you may want to use
19. H2 – Expansion Header for ROHM Breakout Boards/Generic Interface (4 Pin – ADC/GPIO x2)

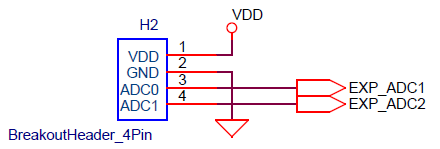
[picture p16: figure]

  b. This header is an expansion header to connect any additional ADC/GPIO x2 based sensors that you may want to use
20. H1 - Expansion Header for ROHM Breakout Boards/Generic Interface (4 Pin – ADC/GPIO x2)

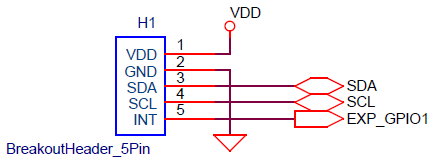
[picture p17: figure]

  b. This header is an expansion header to connect any additional I²C + GPIOx1 based sensors that you may want to use
21. KNOWLES SPM0423HD4H-WB Digital Microphone
22. U13 Top Left Corner KX022 Accelerometer
23. U16 Top Right Corner KX022 Accelerometer
24. U14 Bot Left Corner KX022 Accelerometer
25. U15 Bot Right Corner KX022 Accelerometer

# General Board Software Explanation

Software explanations will differ, depending on the application processor you plan to use. Therefore, please see this shield’s repository for platform guides for using this shield:

https://github.com/ROHMUSDC/ROHM_SensorPlatform_Multi-Sensor-Shield

…/ROHM_SensorPlatform_Multi-Sensor-Shield/Platform Code/

Product Overview SENSORSHLD1-EVK-101 03 May, 2016 – Revision A

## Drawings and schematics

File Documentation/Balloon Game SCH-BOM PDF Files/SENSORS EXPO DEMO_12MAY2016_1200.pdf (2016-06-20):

D | D

# Sensors Expo 3-IN-1 Board Design

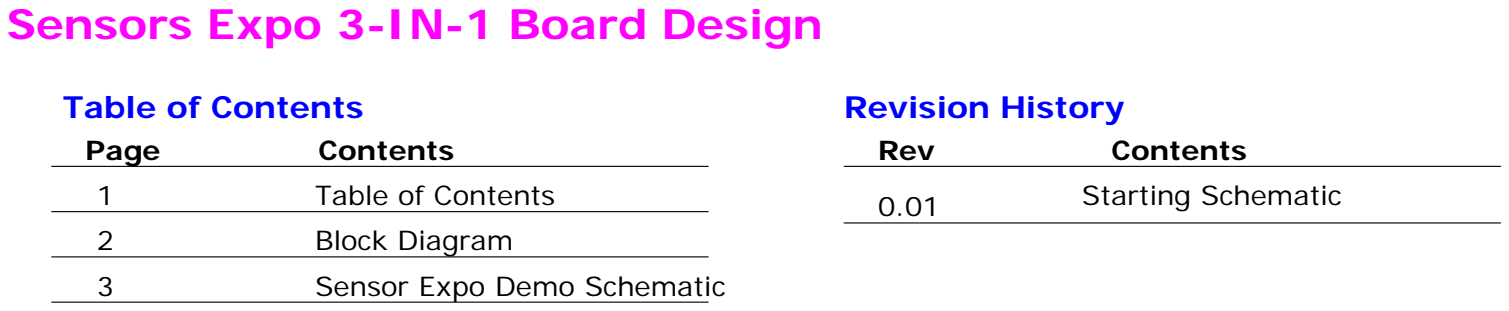
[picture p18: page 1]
Page; Contents; Table of Contents; Block Diagram; Rev; Starting Schematic 0.01; Revision History; Sensor Expo Demo Schematic; Title

2016 Sensor Expo Demo

Table of Content

Size B B B | Document Number ROHM_DEMO_2016 ROHM_DEMO_2016 ROHM_DEMO_2016 | Rev 0.01 0.01 0.01

Date: Thursday, May 12, 2016 Thursday, May 12, 2016 Thursday, May 12, 2016 | Sheet 1 1 1 of 5 5 5

D | D

# LEFT

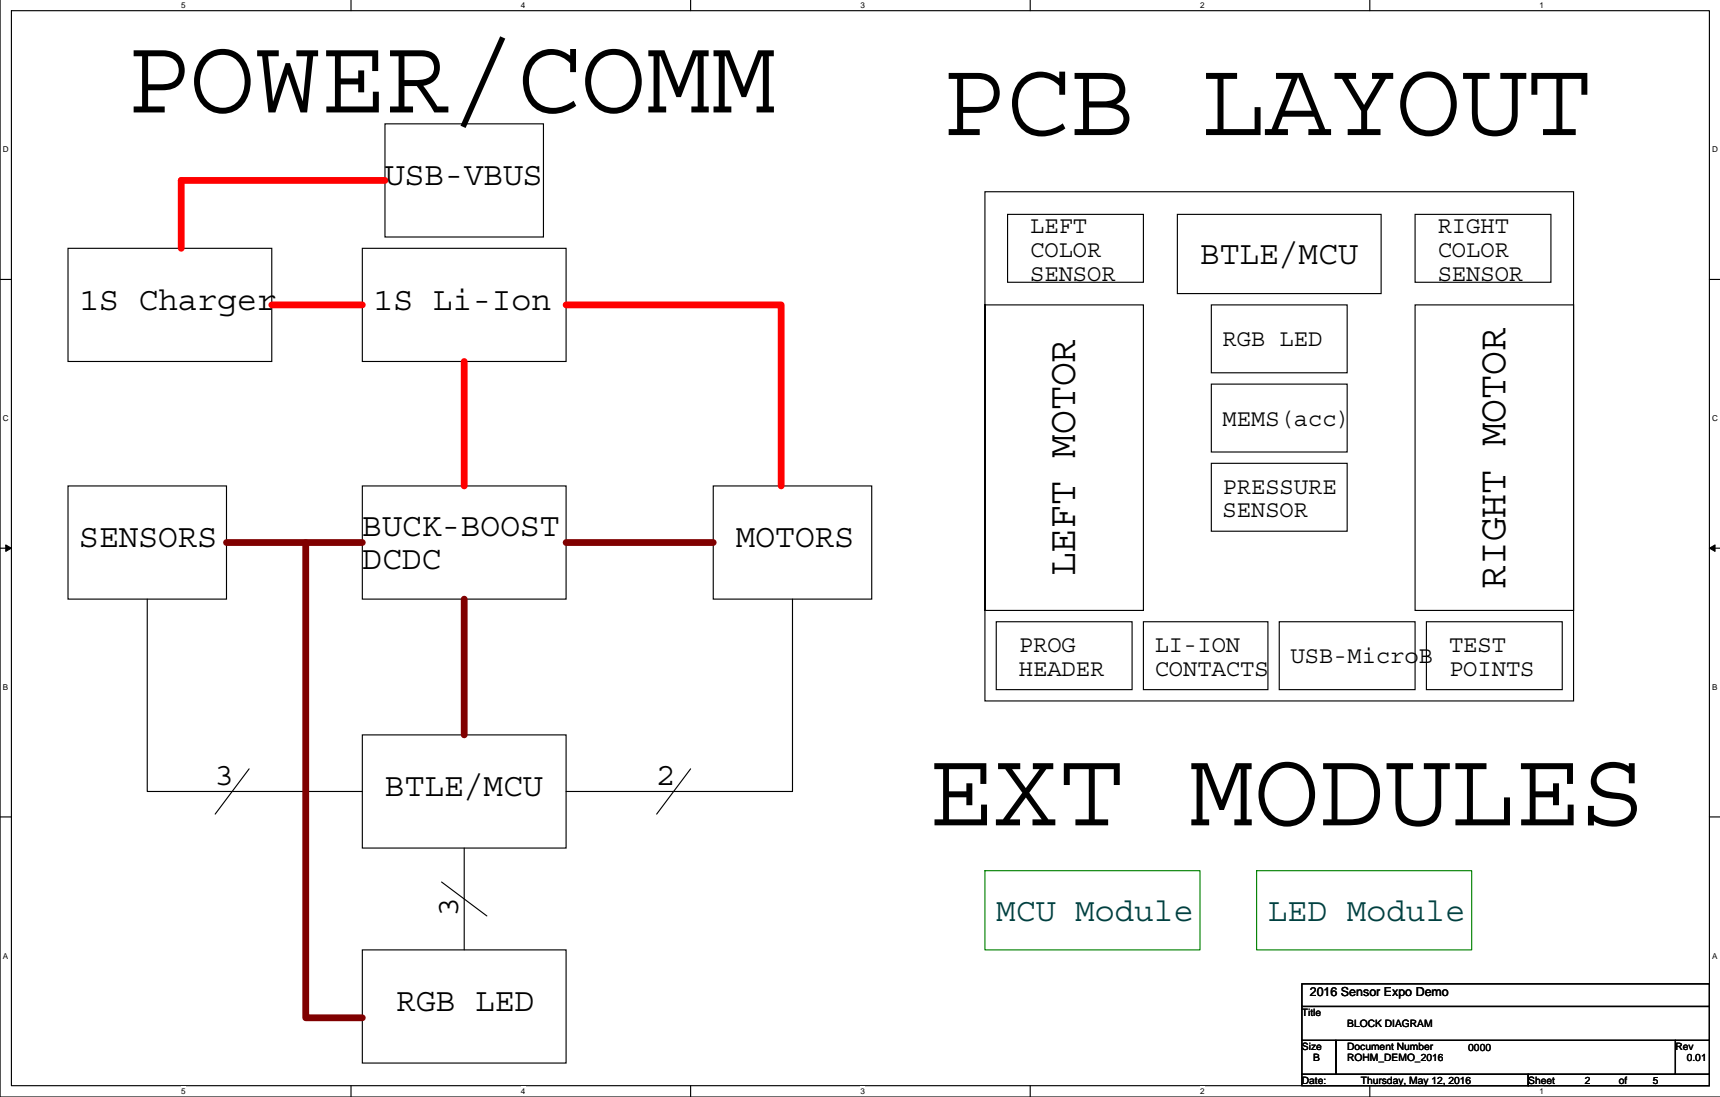
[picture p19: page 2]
A LEFT MOTOR; COLOR SENSOR; RGB LED; MEMS(acc); LI-ION CONTACTS; RIGHT MOTOR; RIGHT COLOR SENSOR; PRESSURE SENSOR; BTLE/MCU; PROG HEADER; TEST POINTS; BUCK-BOOST DCDC; 1S Li-Ion; SENSORS; MOTORS; POWER/COMM; PCB LAYOUT; 1S Charger; USB-VBUS; USB-MicroB EXT MODULES; BLOCK DIAGRAM; MCU Module; LED Module

2016 Sensor Expo Demo

B B B | ROHM_DEMO_2016 ROHM_DEMO_2016 ROHM_DEMO_2016 | 0.01 0.01 0.01

Thursday, May 12, 2016 Thursday, May 12, 2016 Thursday, May 12, 2016 | 2 2 2 5 5 5

# GENERAL CONSIDERATIONS

# 1) Test Points (SPI_*) needs to be in a

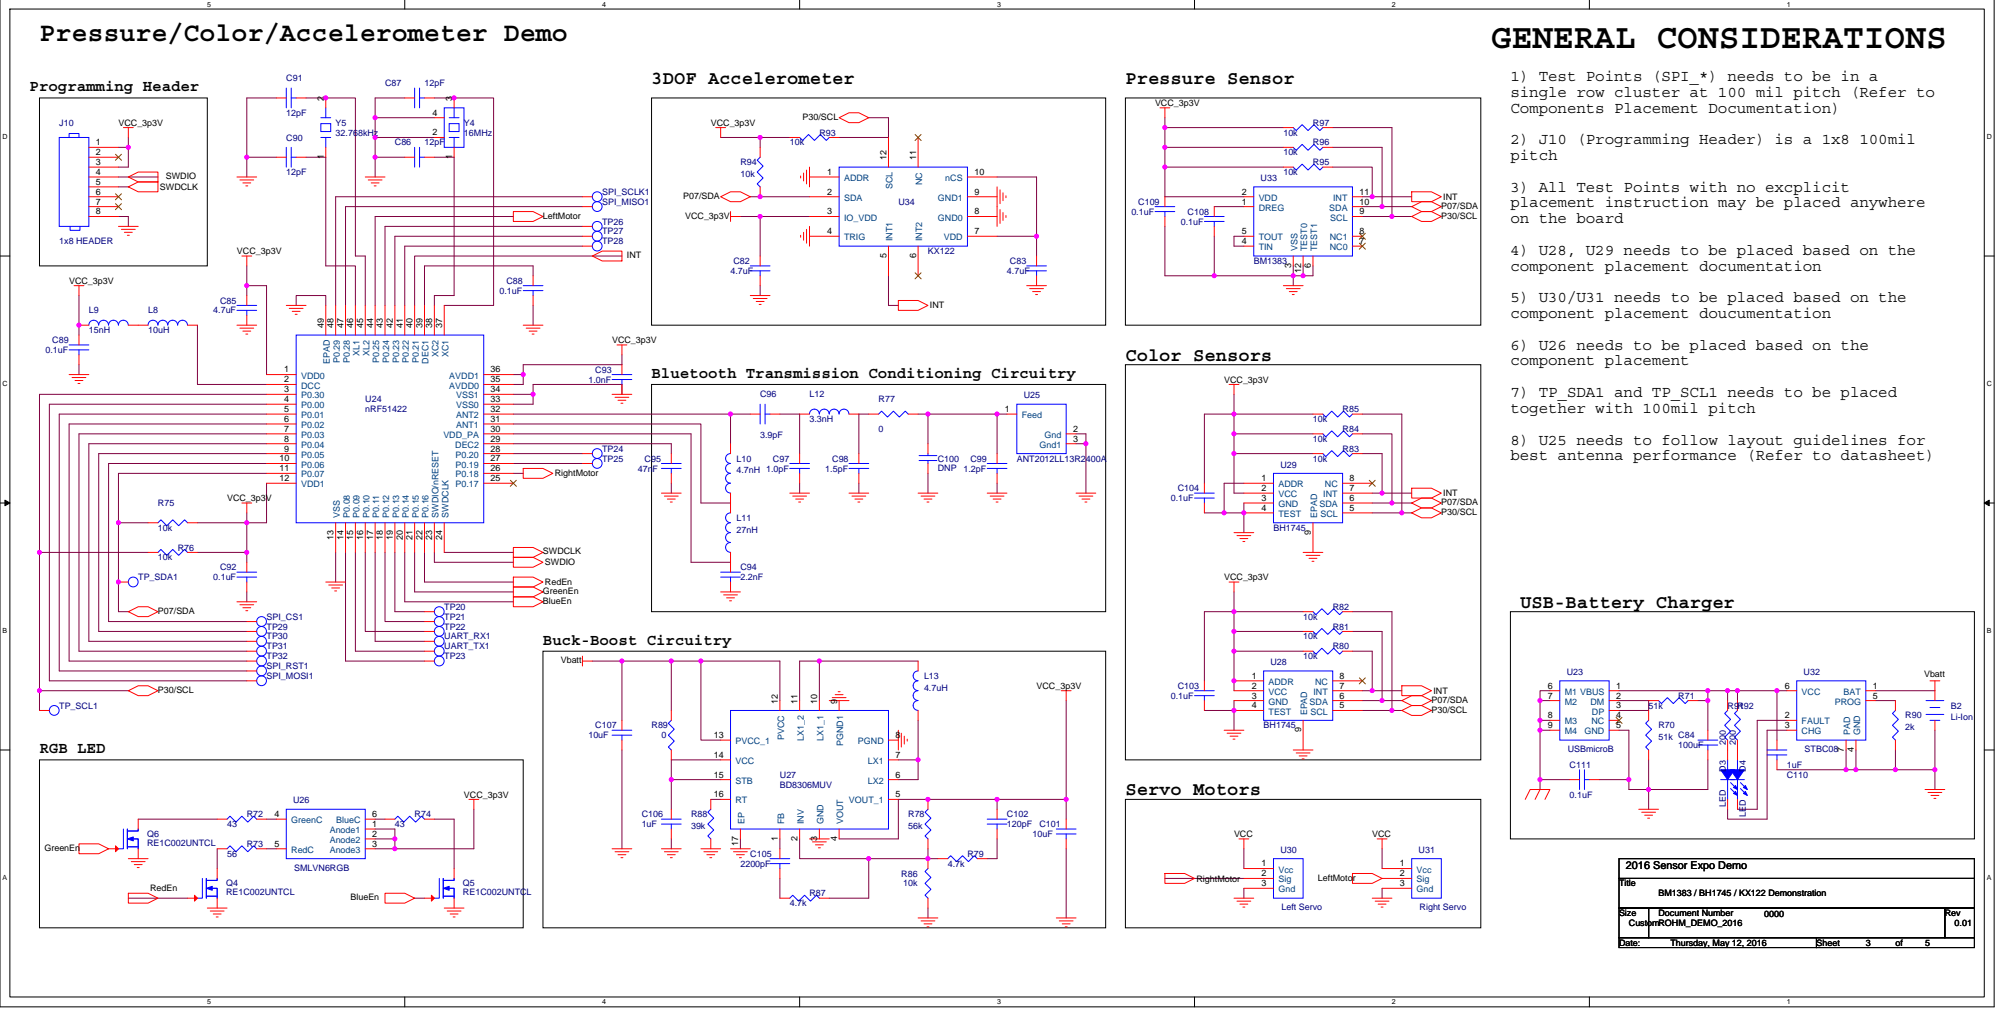
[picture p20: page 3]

Pressure/Color/Accelerometer Demo

single row cluster at 100 mil pitch (Refer to
Components Placement Documentation)

3) All Test Points with no excplicit
placement instruction may be placed anywhere
on the board

4) U28, U29 needs to be placed based on the
component placement documentation

5) U30/U31 needs to be placed based on the
component placement doucumentation

P0.17 25 P0.18 26 P0.19 27 P0.20 28 DEC2 29 VDD_PA 30 ANT1 31 ANT2 32 VSS0 33 VSS1 34 AVDD0 35 AVDD1 36 XC¹ ³⁷ XC² ³⁸ DEC¹ ³⁹ P⁰.21 40 P⁰.22 41 P⁰.23 42 P⁰.24 43 P⁰.25 44 XL2 45 XL1 46 P⁰.28 47 P⁰.29 48 EPAD ⁴⁹

6) U26 needs to be placed based on the
component placement

Bluetooth Transmission Conditioning Circuitry

7) TP_SDA1 and TP_SCL1 needs to be placed
together with 100mil pitch

8) U25 needs to follow layout guidelines for
best antenna performance (Refer to datasheet)

Size Size Size Custom Custom Custom | Document Number Document Number Document Number 0000 0000 0000 ROHM_DEMO_2016 ROHM_DEMO_2016 ROHM_DEMO_2016 | Rev Rev Rev 0.01 0.01 0.01

Date: Date: Date: Thursday, May 12, 2016 Thursday, May 12, 2016 Thursday, May 12, 2016 | Sheet Sheet Sheet 3 3 3 of of of 5 5 5

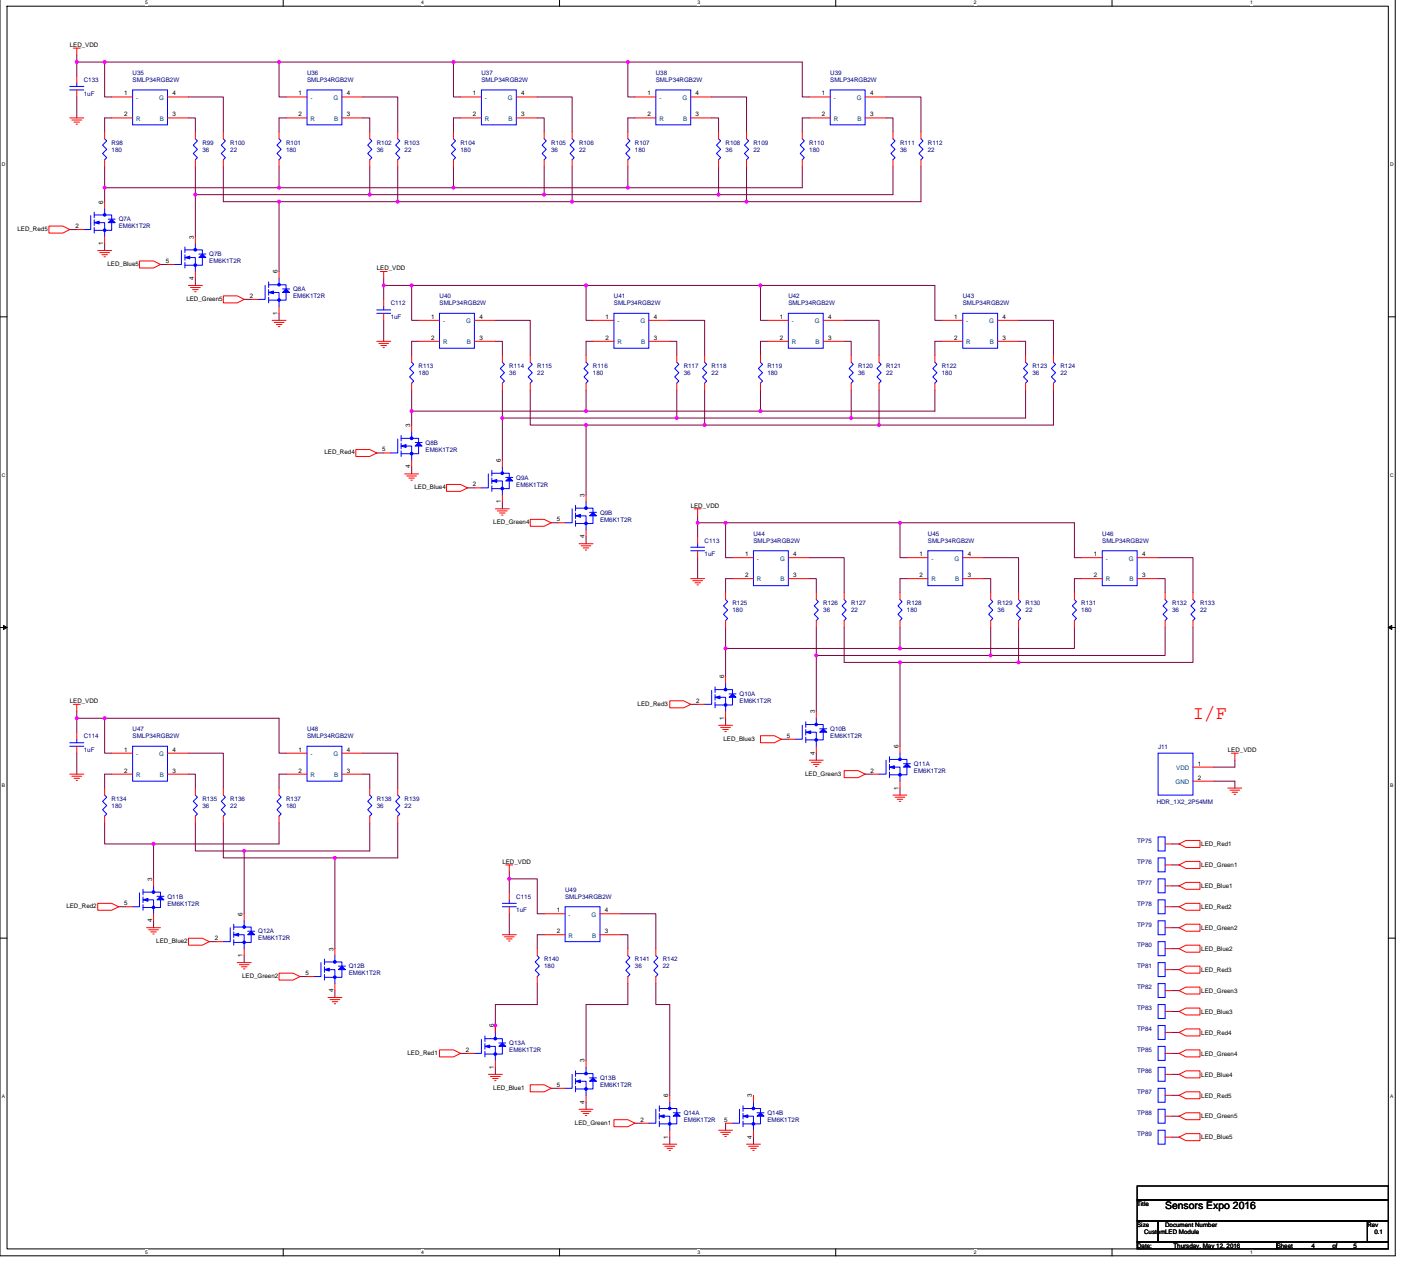
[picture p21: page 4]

# DC/DC

I/F

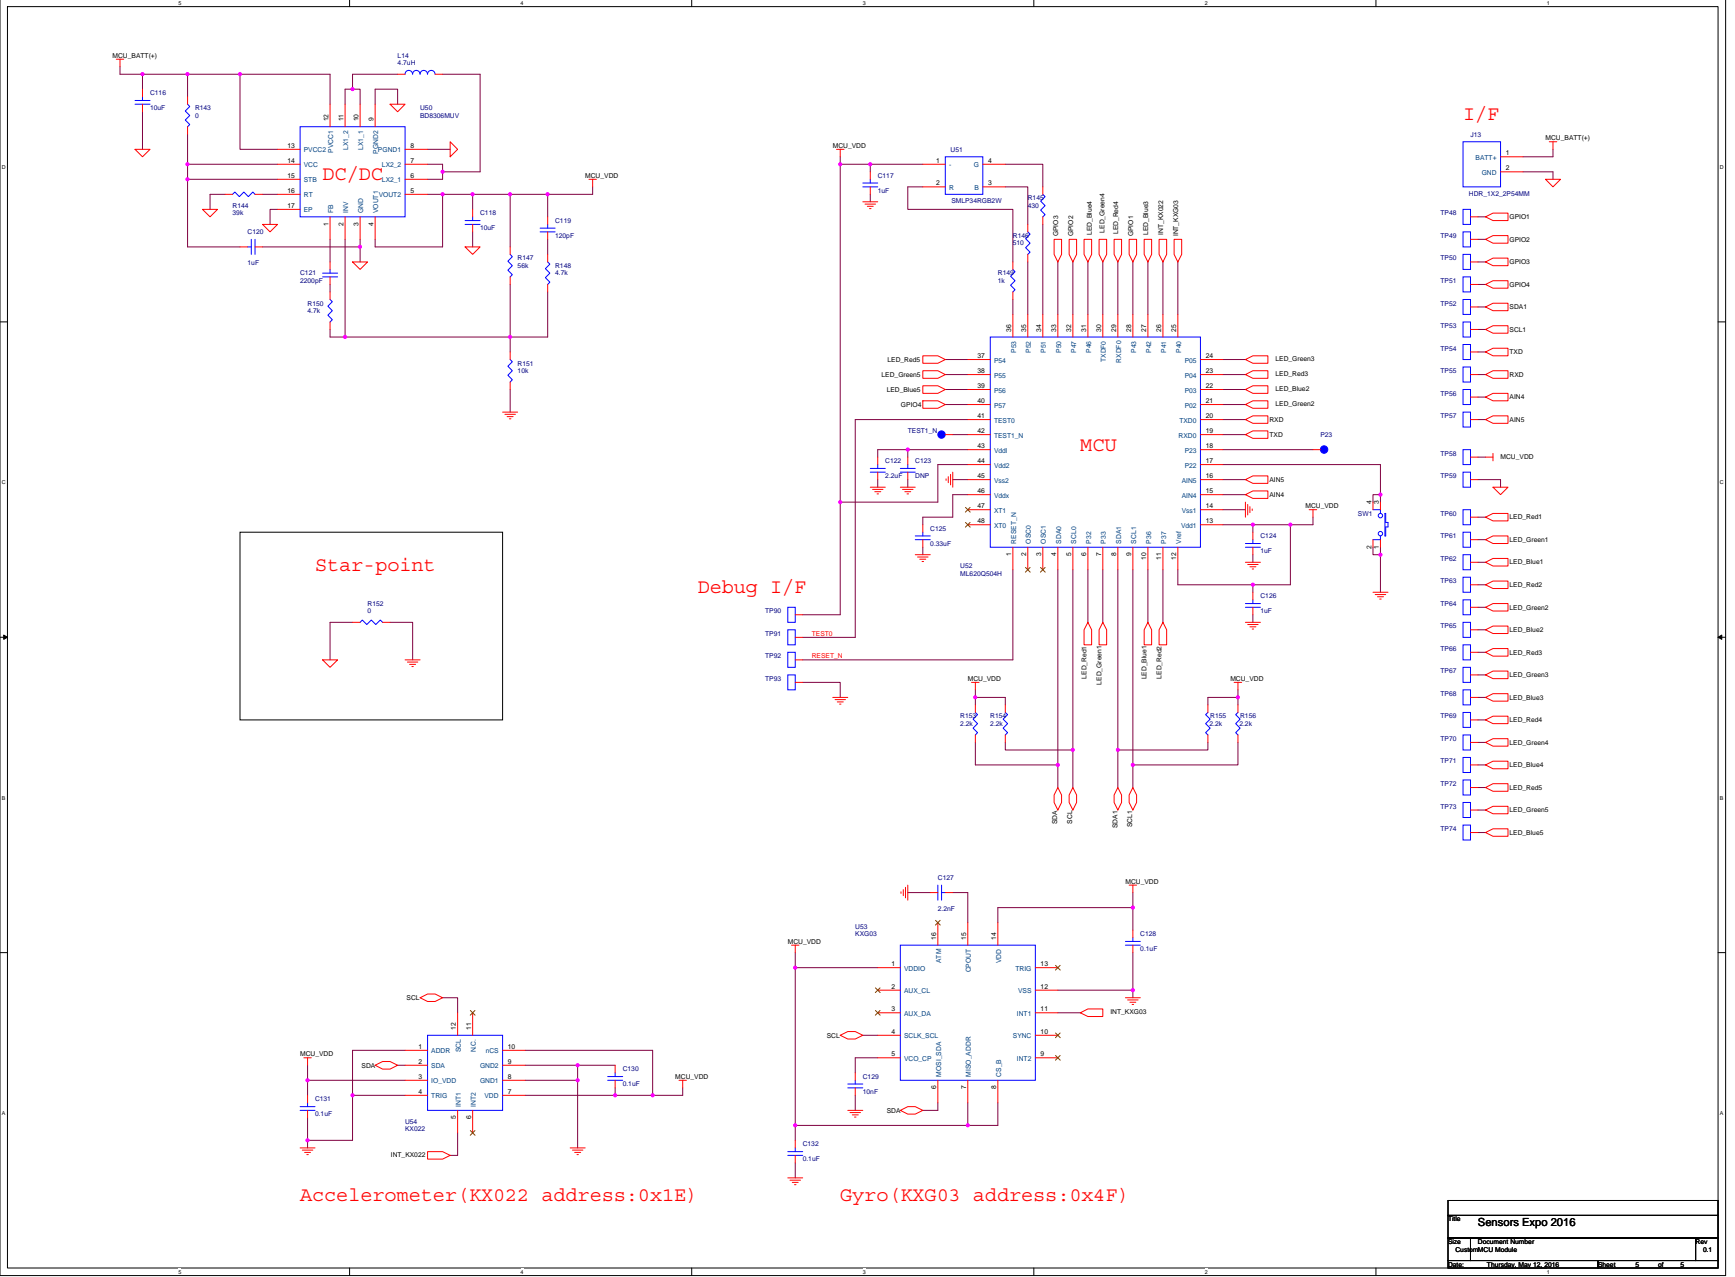
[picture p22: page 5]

Custom Custom Custom | MCU Module MCU Module MCU Module | 0.1 0.1 0.1

Thursday, May 12, 2016 Thursday, May 12, 2016 Thursday, May 12, 2016 | 5 5 5

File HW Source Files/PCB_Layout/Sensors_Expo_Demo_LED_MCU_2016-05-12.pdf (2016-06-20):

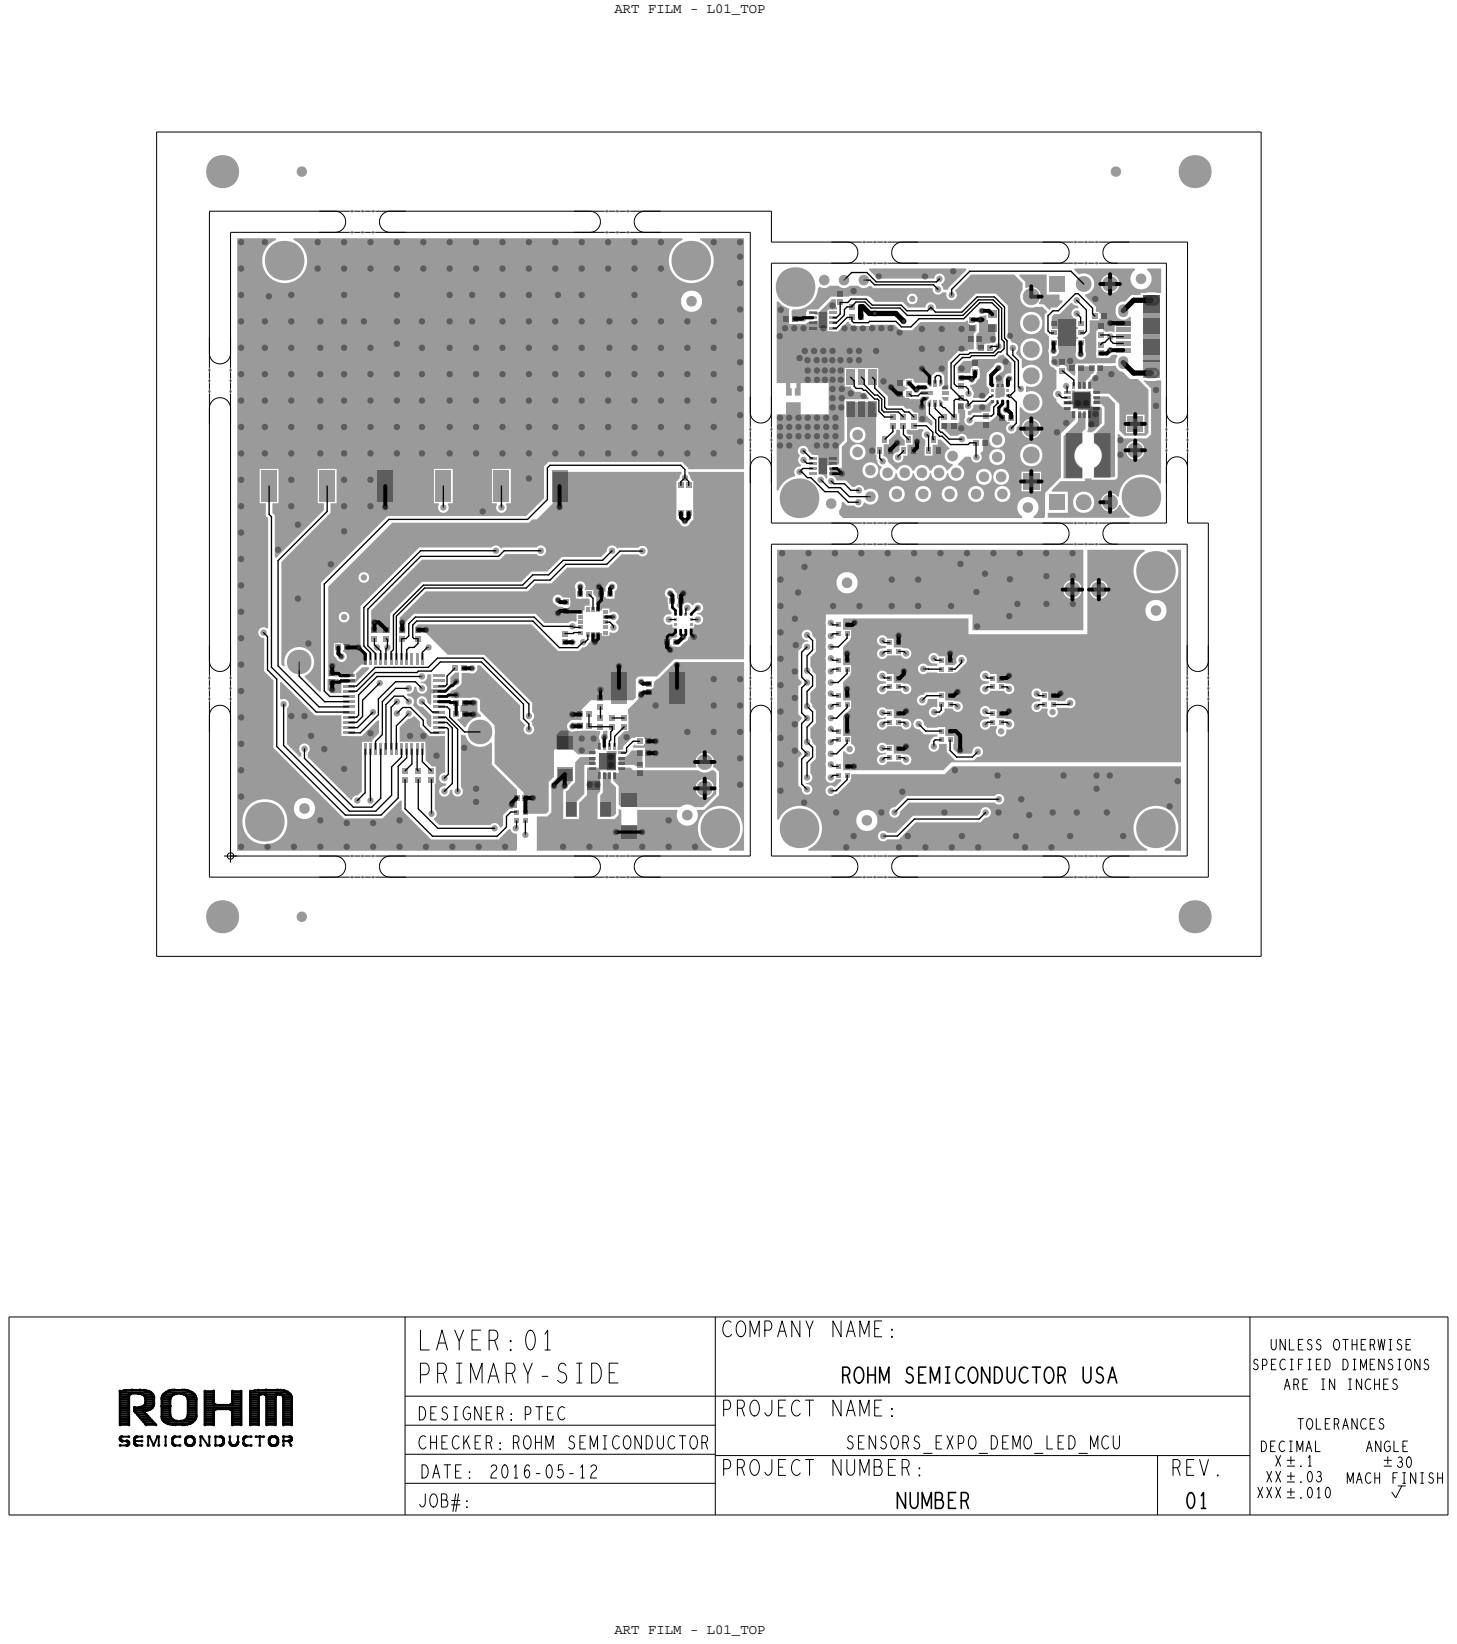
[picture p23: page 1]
ART FILM - L01_TOP; ANGLE; TOLERANCES; MACH FINISH; DECIMAL; REV.; XXX 01; ROHM; SEMICONDUCTOR USA; SENSORS_EXPO_DEMO_LED_MCU; NUMBER; COMPANY NAME:; PROJECT; NAME:; NUMBER:; PTEC; ROHM SEMICONDUCTOR; LAYER: PRIMARY-SIDE; DESIGNER:; DATE:; CHECKER:; JOB#:

UNLESS OTHERWISE
SPECIFIED DIMENSIONS
ARE IN INCHES

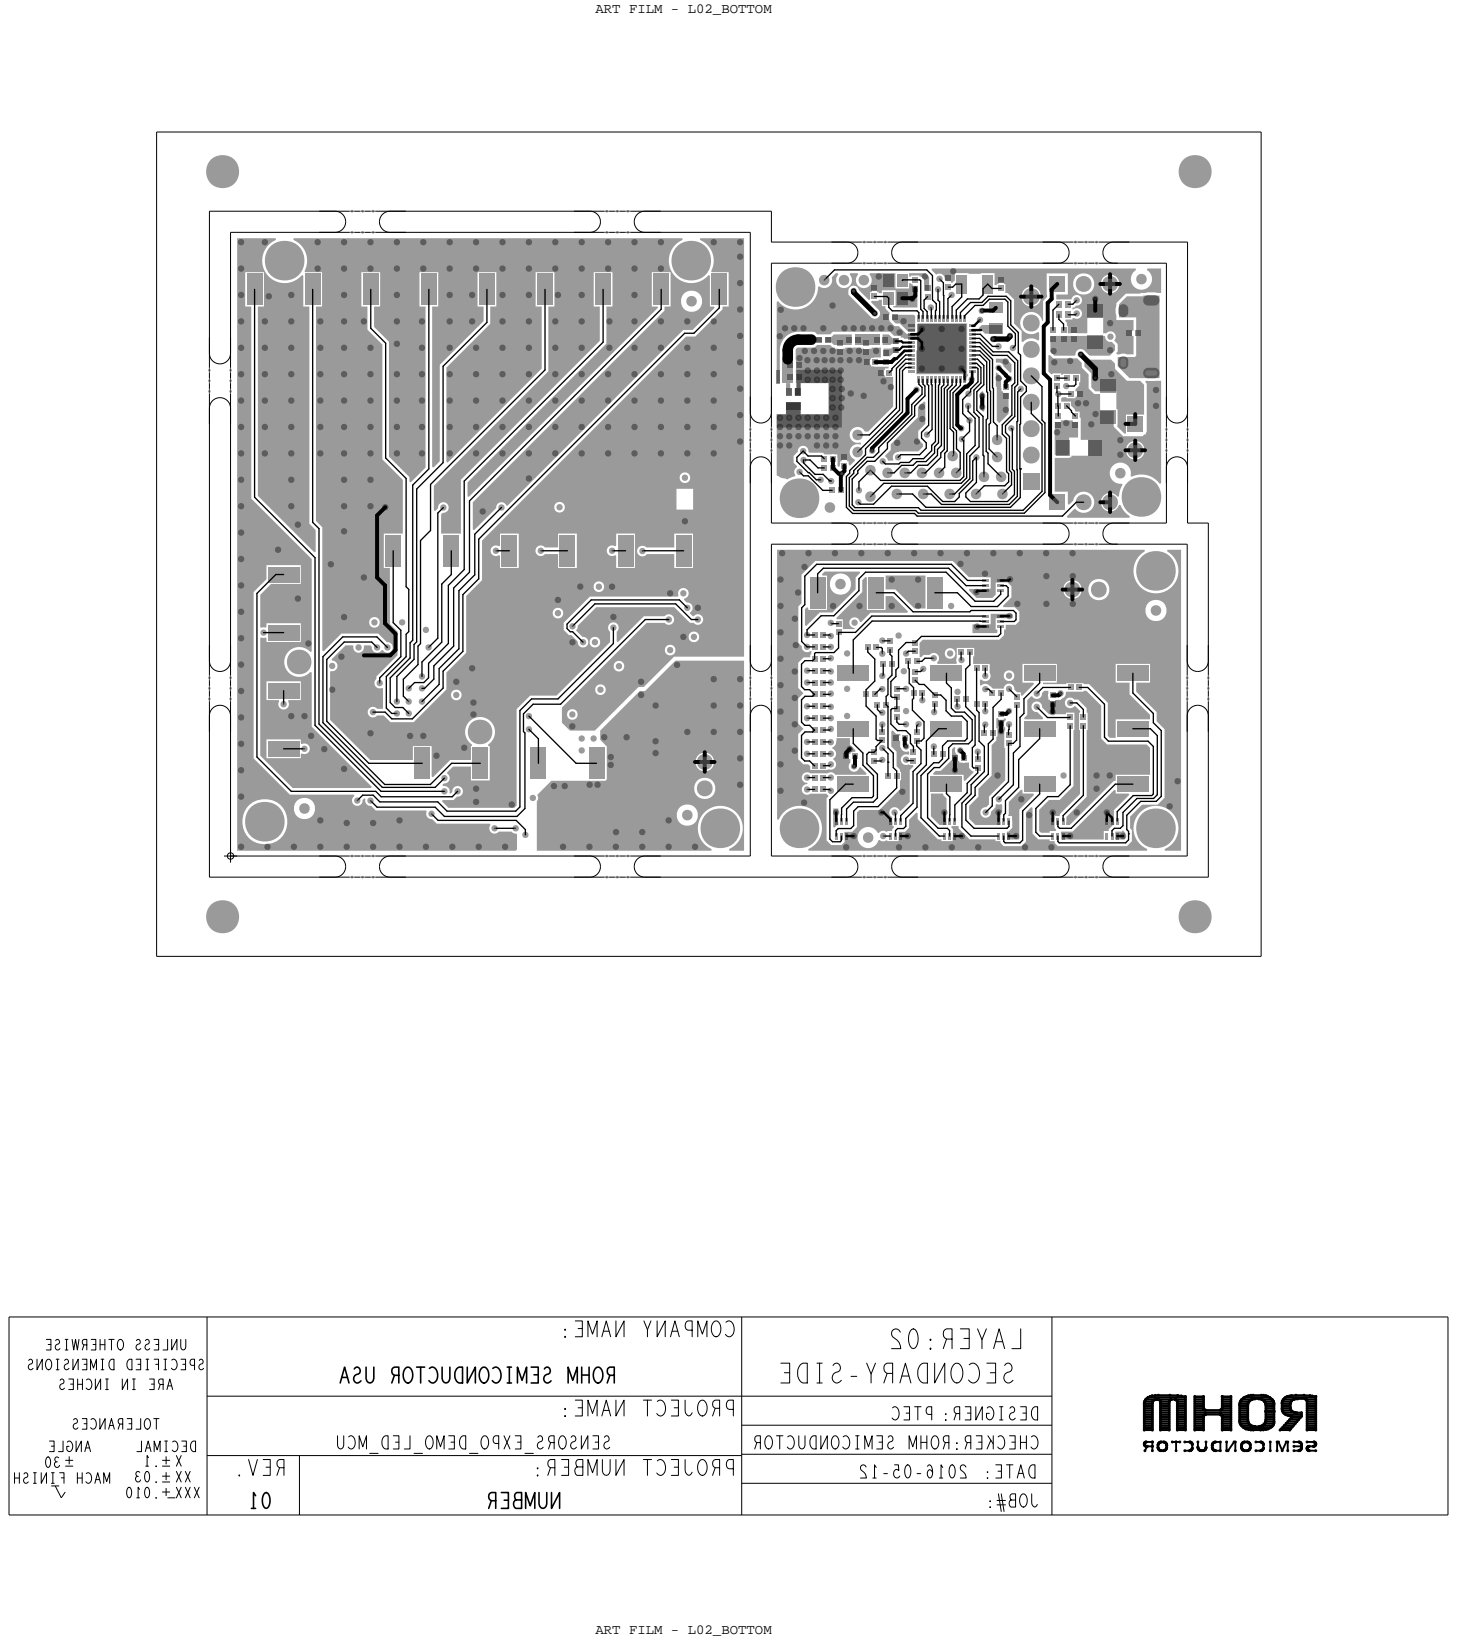
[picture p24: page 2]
ART FILM - L02_BOTTOM; LAYER:; DATE:; CHECKER:; DESIGNER:; JOB#:; PTEC; SECONDARY-SIDE; ROHM SEMICONDUCTOR; COMPANY NAME:; PROJECT NAME:; PROJECT NUMBER:; NUMBER; SENSORS_EXPO_DEMO_LED_MCU; REV.; DECIMAL .1 .03 .010 XXX; UNLESS OTHERWISE; TOLERANCES; ANGLE; SPECIFIED DIMENSIONS; MACH FINISH

ROHM SEMICONDUCTOR USA

ARE IN INCHES

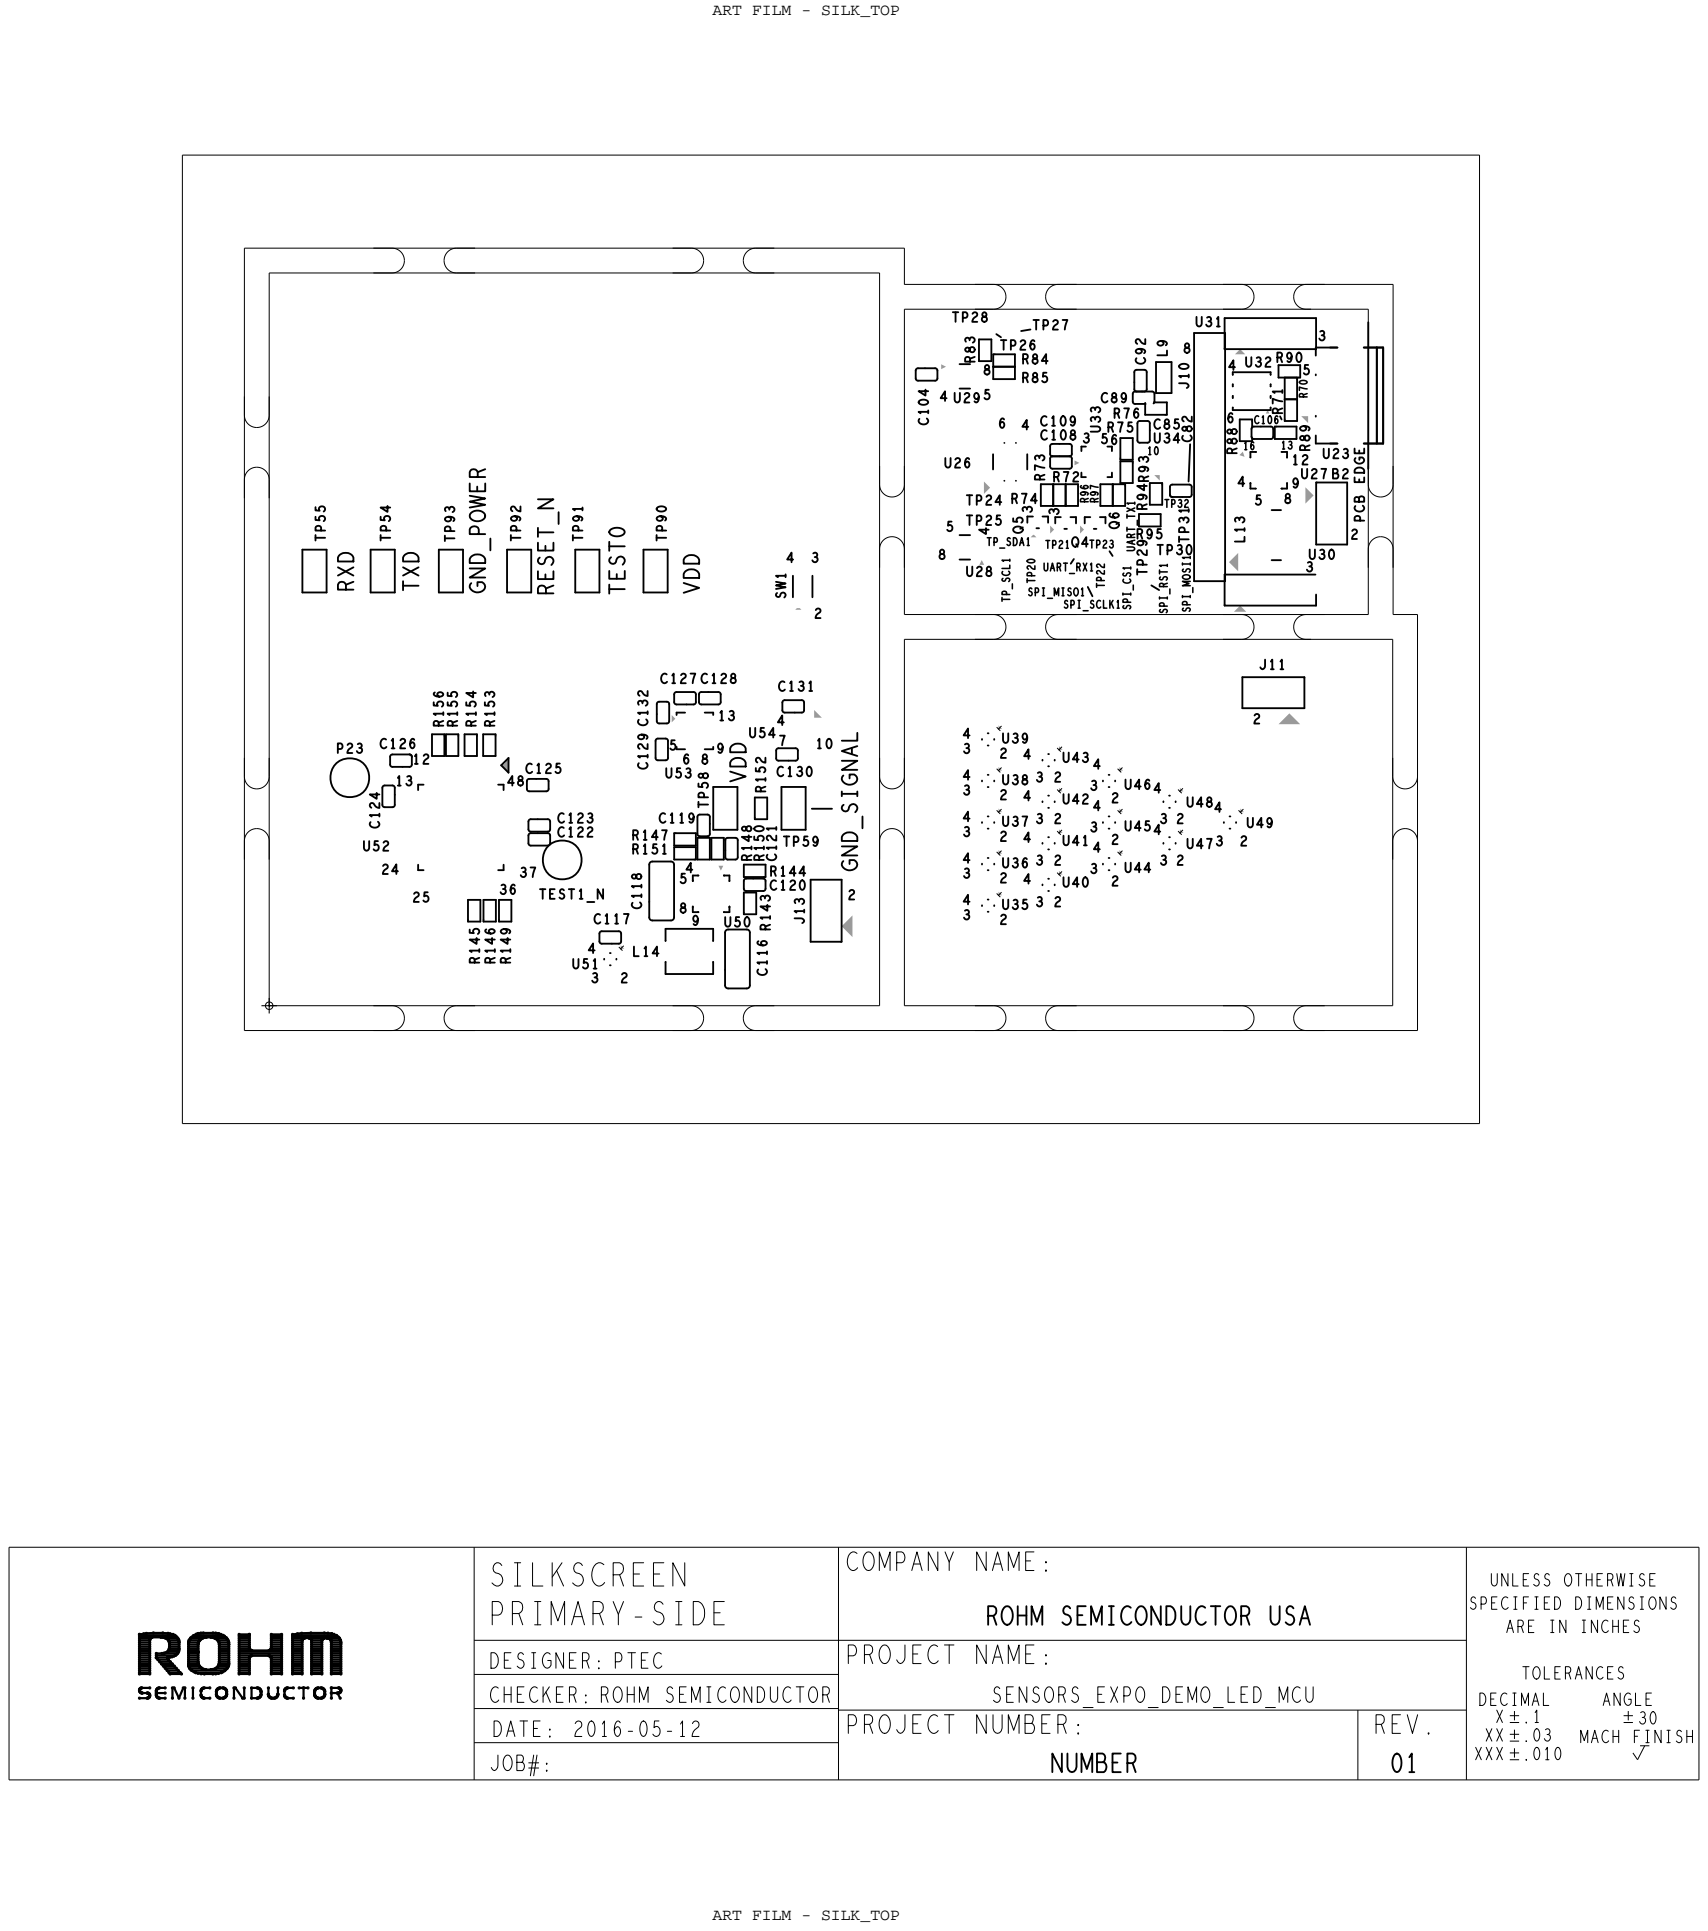
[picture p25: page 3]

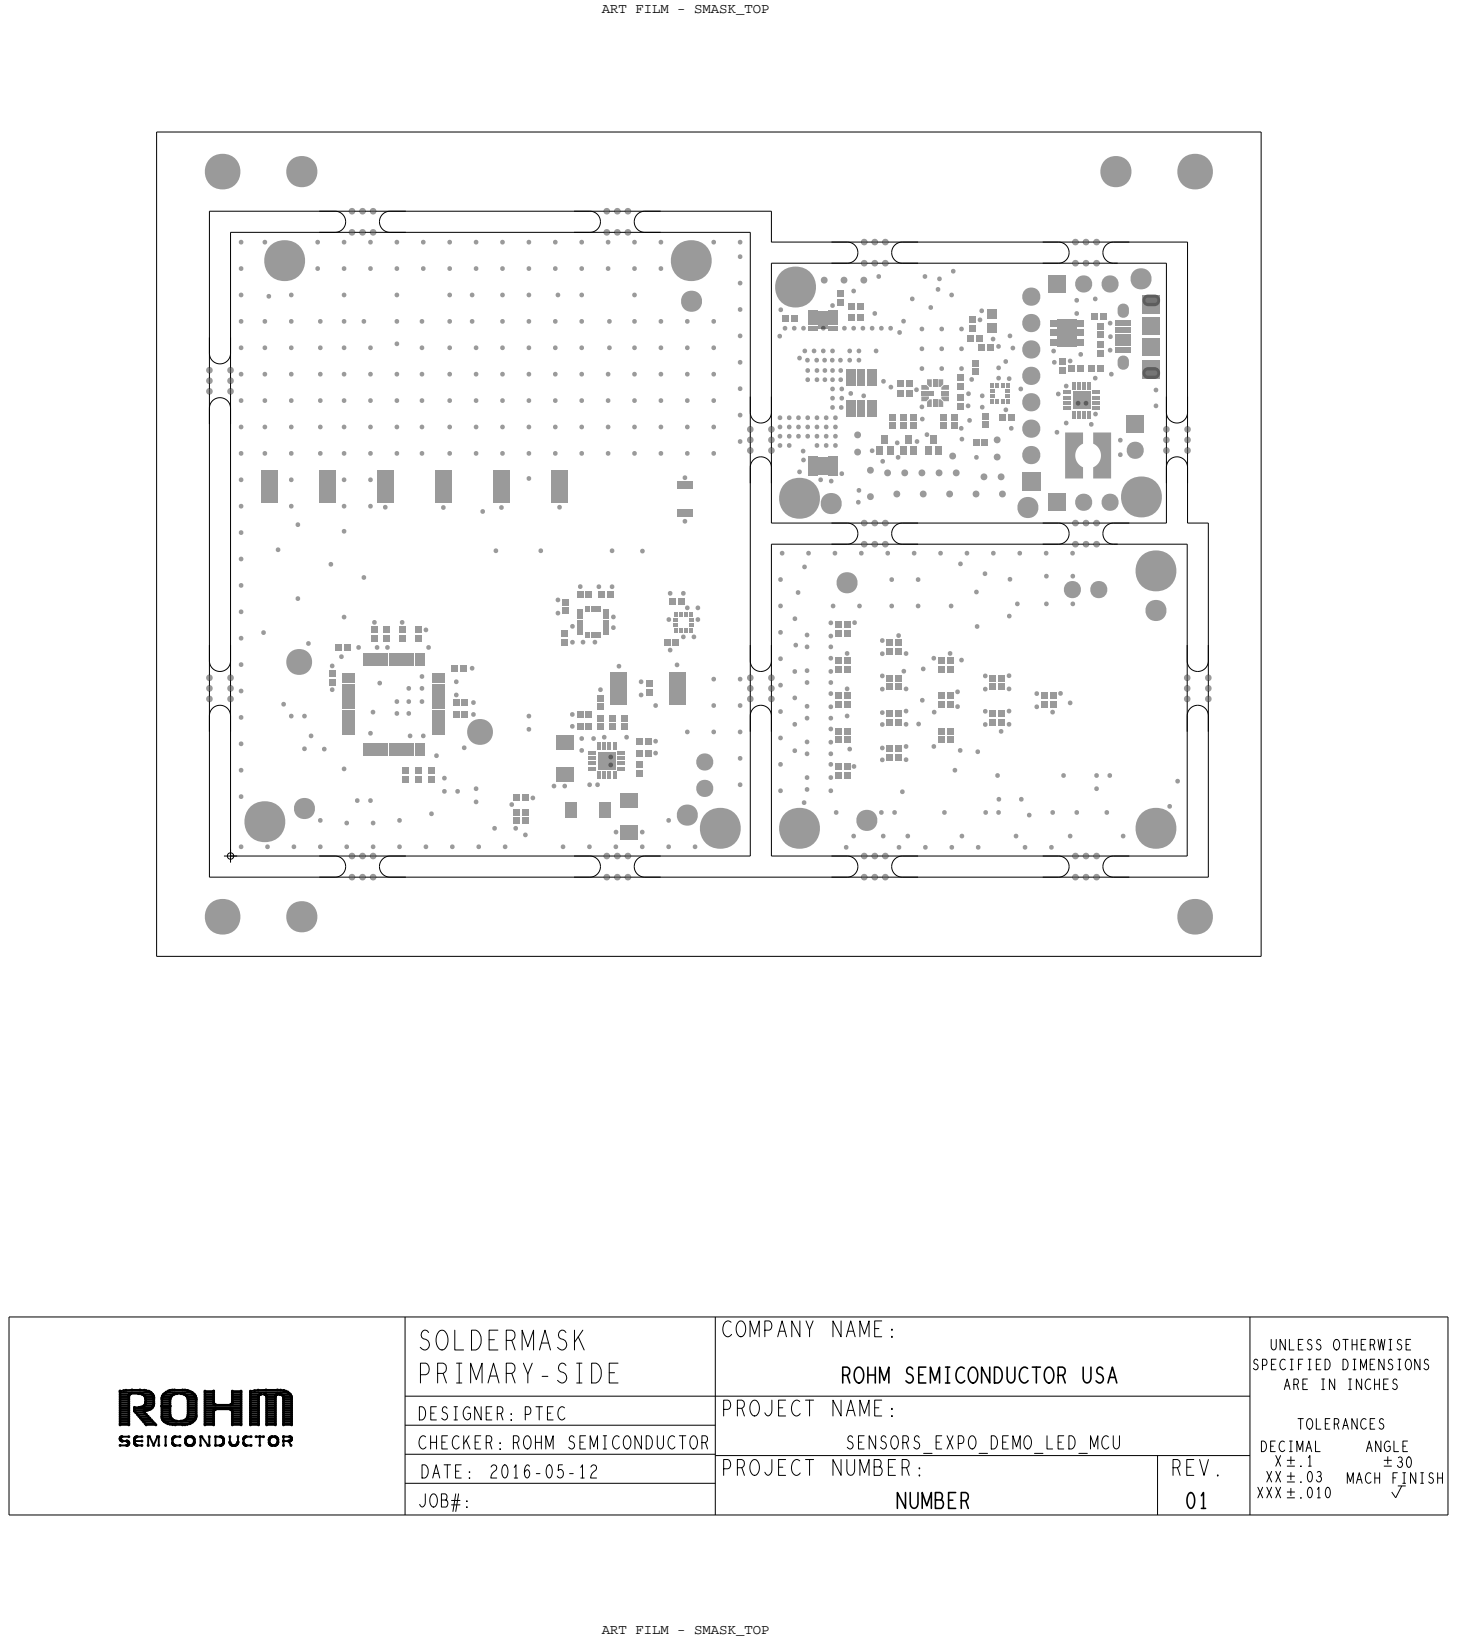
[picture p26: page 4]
ART FILM - SMASK_TOP; ANGLE; TOLERANCES; MACH FINISH; DECIMAL; REV.; XXX 01; ROHM; SEMICONDUCTOR USA; SENSORS_EXPO_DEMO_LED_MCU; NUMBER; COMPANY NAME:; PROJECT; NAME:; NUMBER:; PTEC; ROHM SEMICONDUCTOR; SOLDERMASK; DESIGNER:; DATE:; PRIMARY-SIDE; CHECKER:; JOB#:

UNLESS OTHERWISE
SPECIFIED DIMENSIONS
ARE IN INCHES

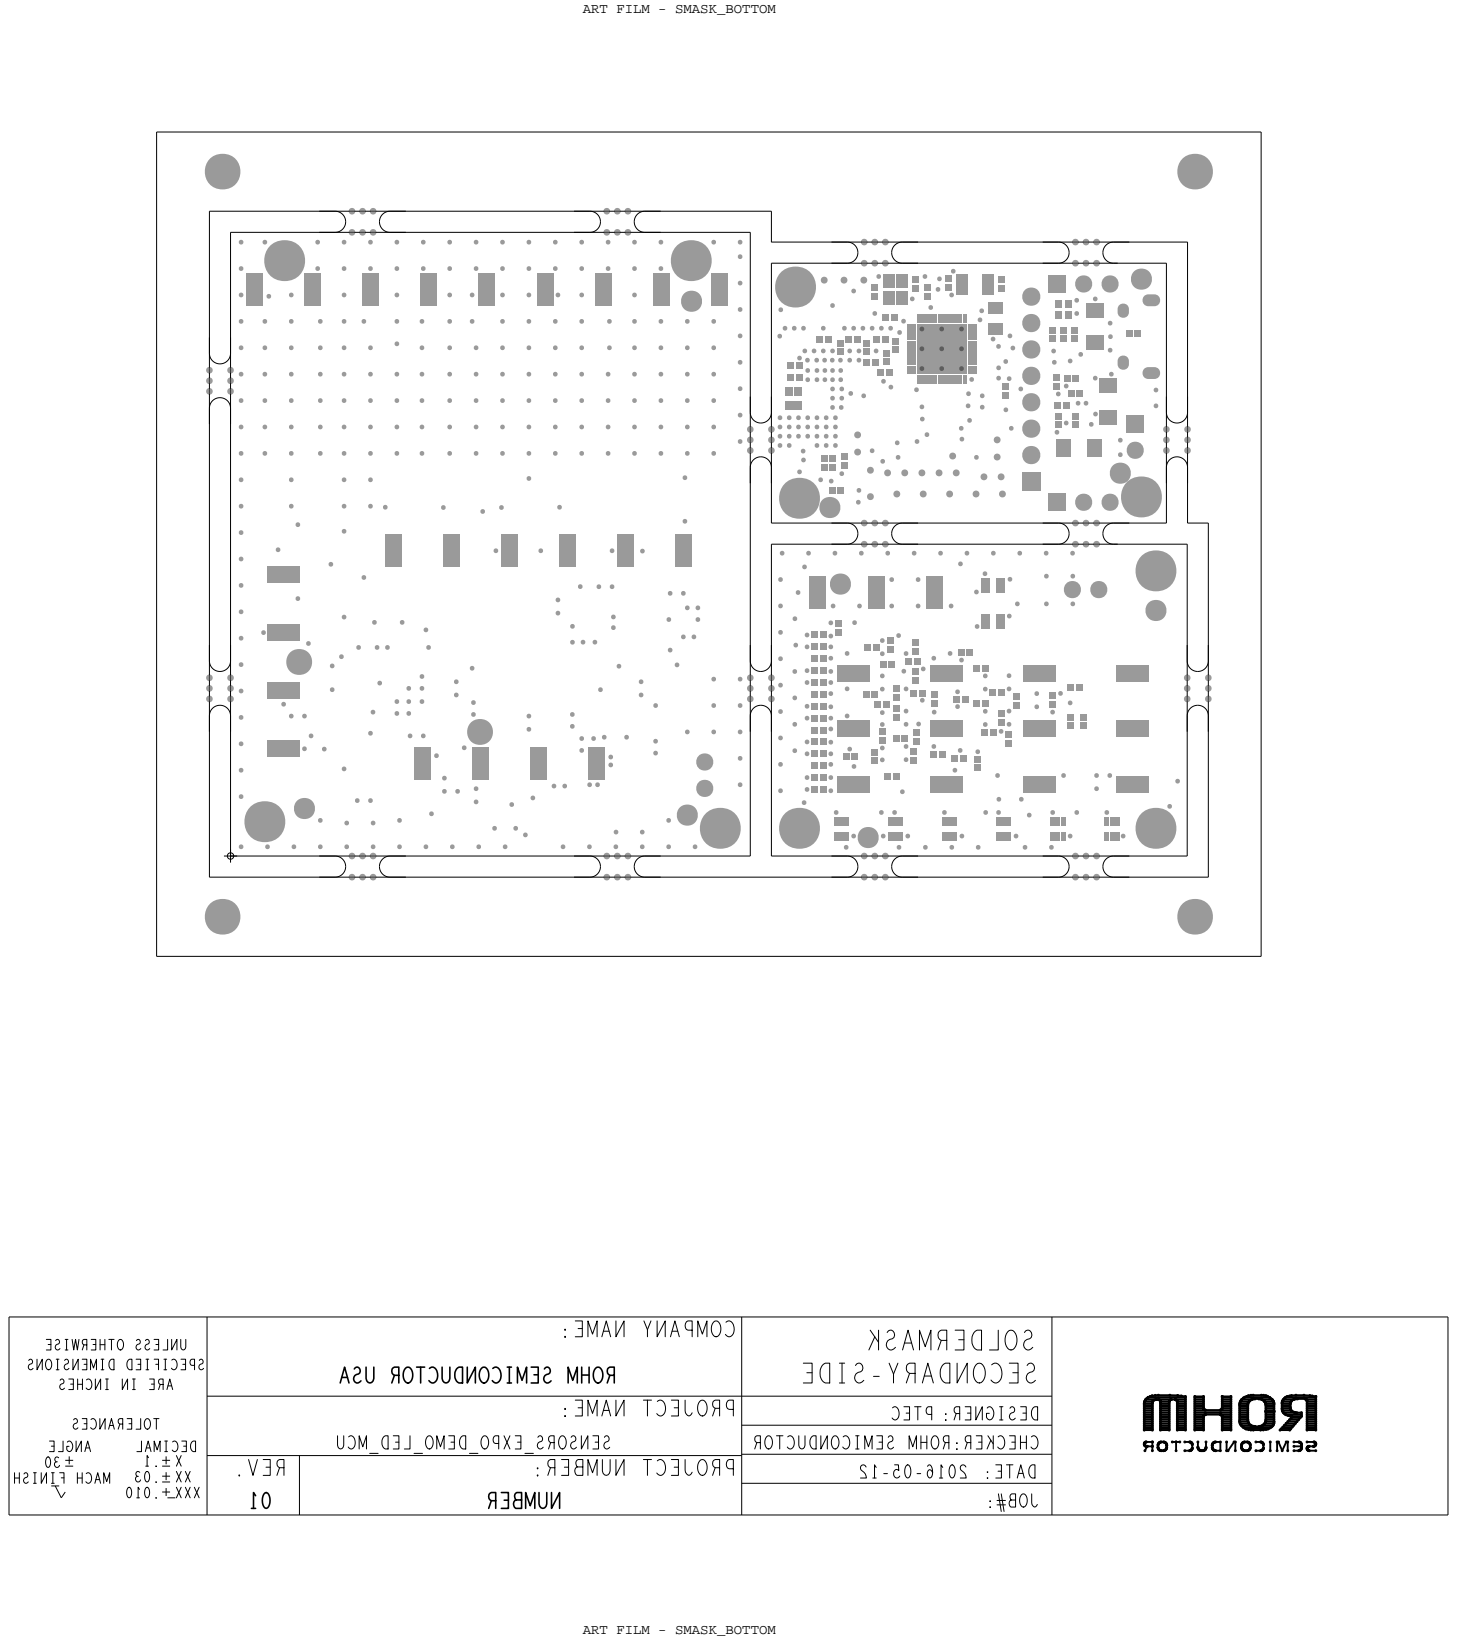
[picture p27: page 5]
ART FILM - SMASK_BOTTOM; DATE:; CHECKER:; DESIGNER:; JOB#:; SOLDERMASK SECONDARY-SIDE; PTEC; ROHM SEMICONDUCTOR; COMPANY NAME:; PROJECT NAME:; PROJECT NUMBER:; NUMBER; SENSORS_EXPO_DEMO_LED_MCU; REV.; DECIMAL .1 .03 .010 XXX; UNLESS OTHERWISE; TOLERANCES; ANGLE; SPECIFIED DIMENSIONS; MACH FINISH

ROHM SEMICONDUCTOR USA

ARE IN INCHES

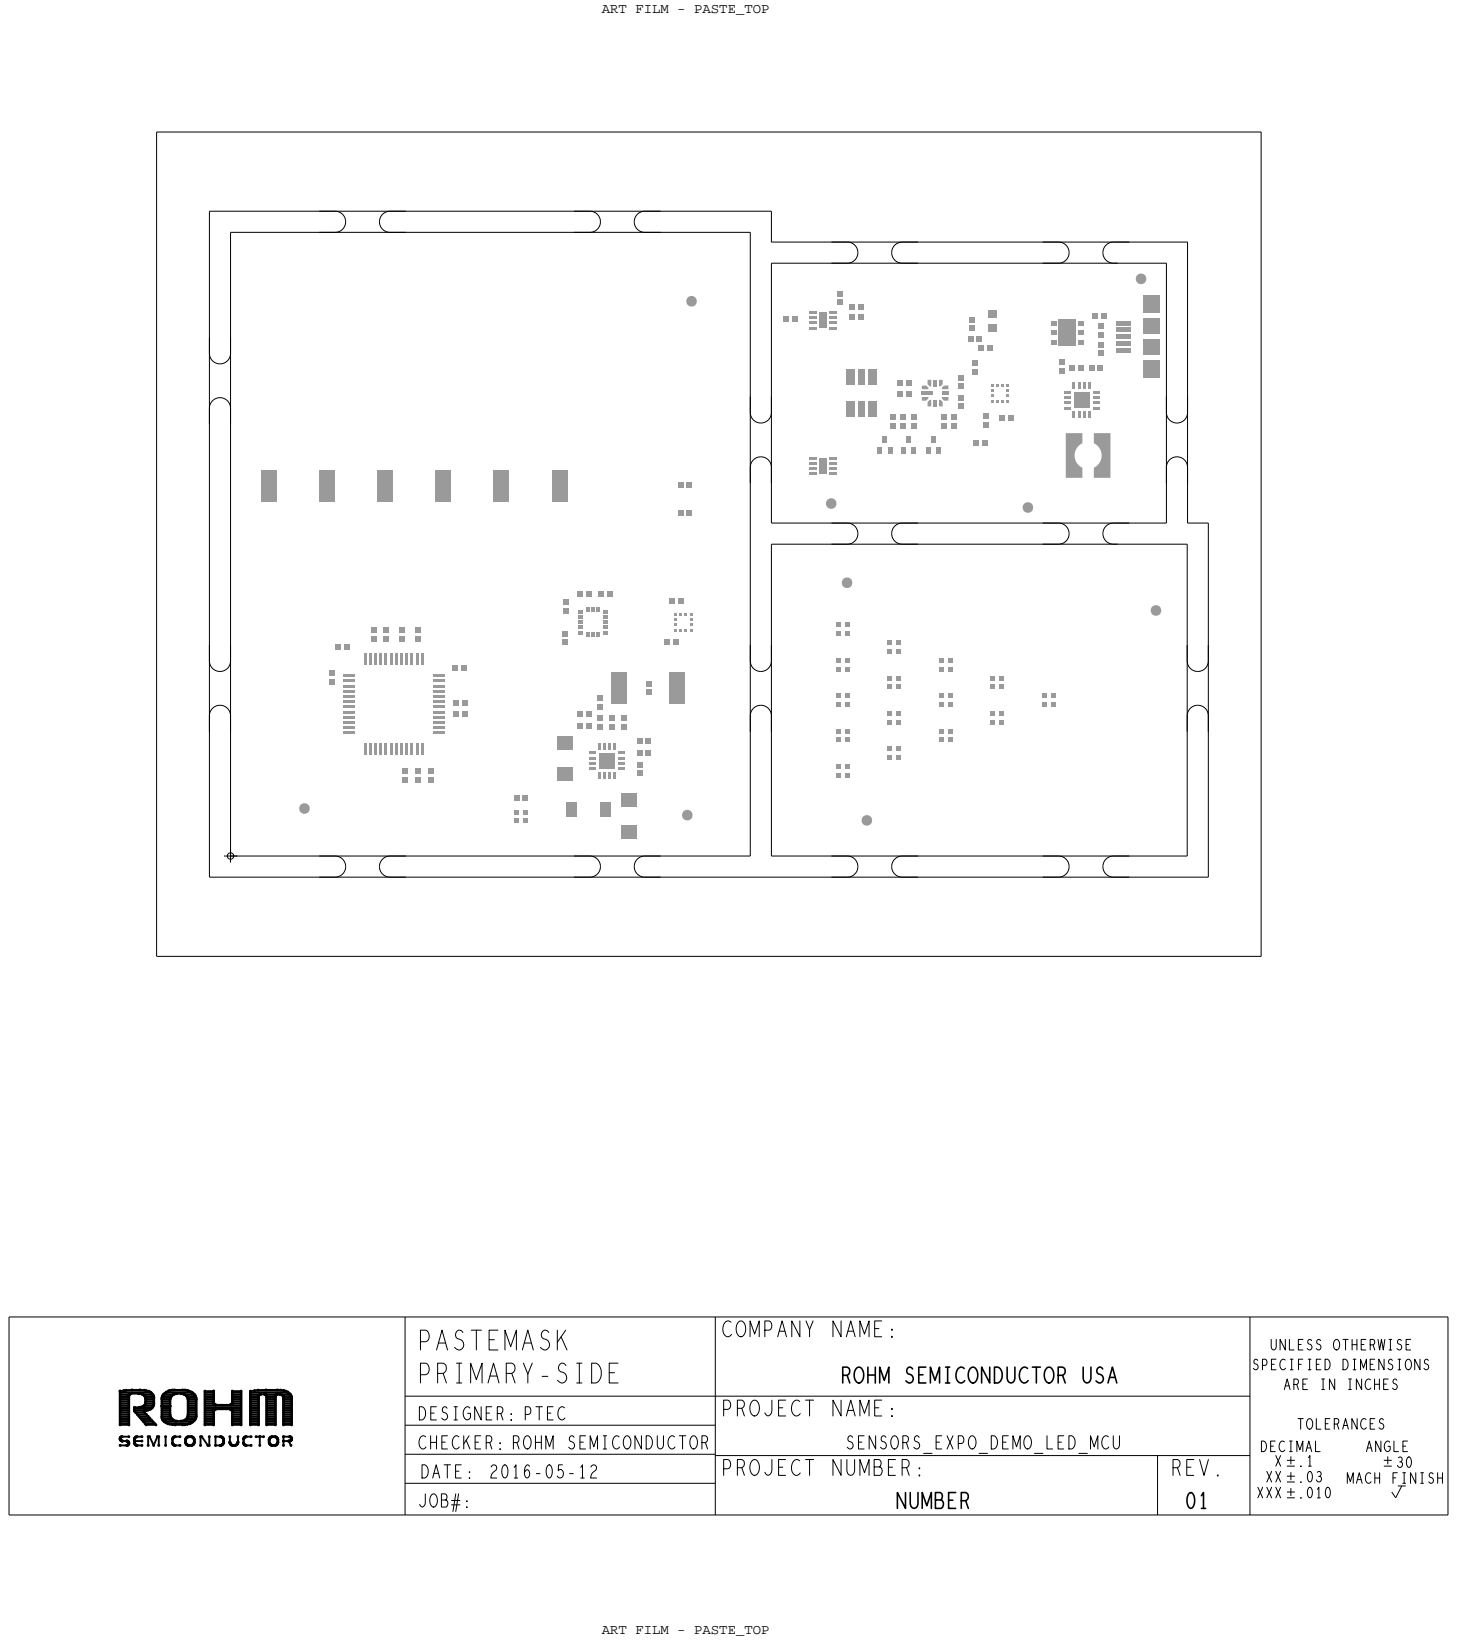
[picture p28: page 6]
ART FILM - PASTE_TOP; ANGLE; TOLERANCES; MACH FINISH; DECIMAL; REV.; XXX 01; ROHM; SEMICONDUCTOR USA; SENSORS_EXPO_DEMO_LED_MCU; NUMBER; COMPANY NAME:; PROJECT; NAME:; NUMBER:; PTEC; ROHM SEMICONDUCTOR; PASTEMASK; DESIGNER:; DATE:; PRIMARY-SIDE; CHECKER:; JOB#:

UNLESS OTHERWISE
SPECIFIED DIMENSIONS
ARE IN INCHES

D

2

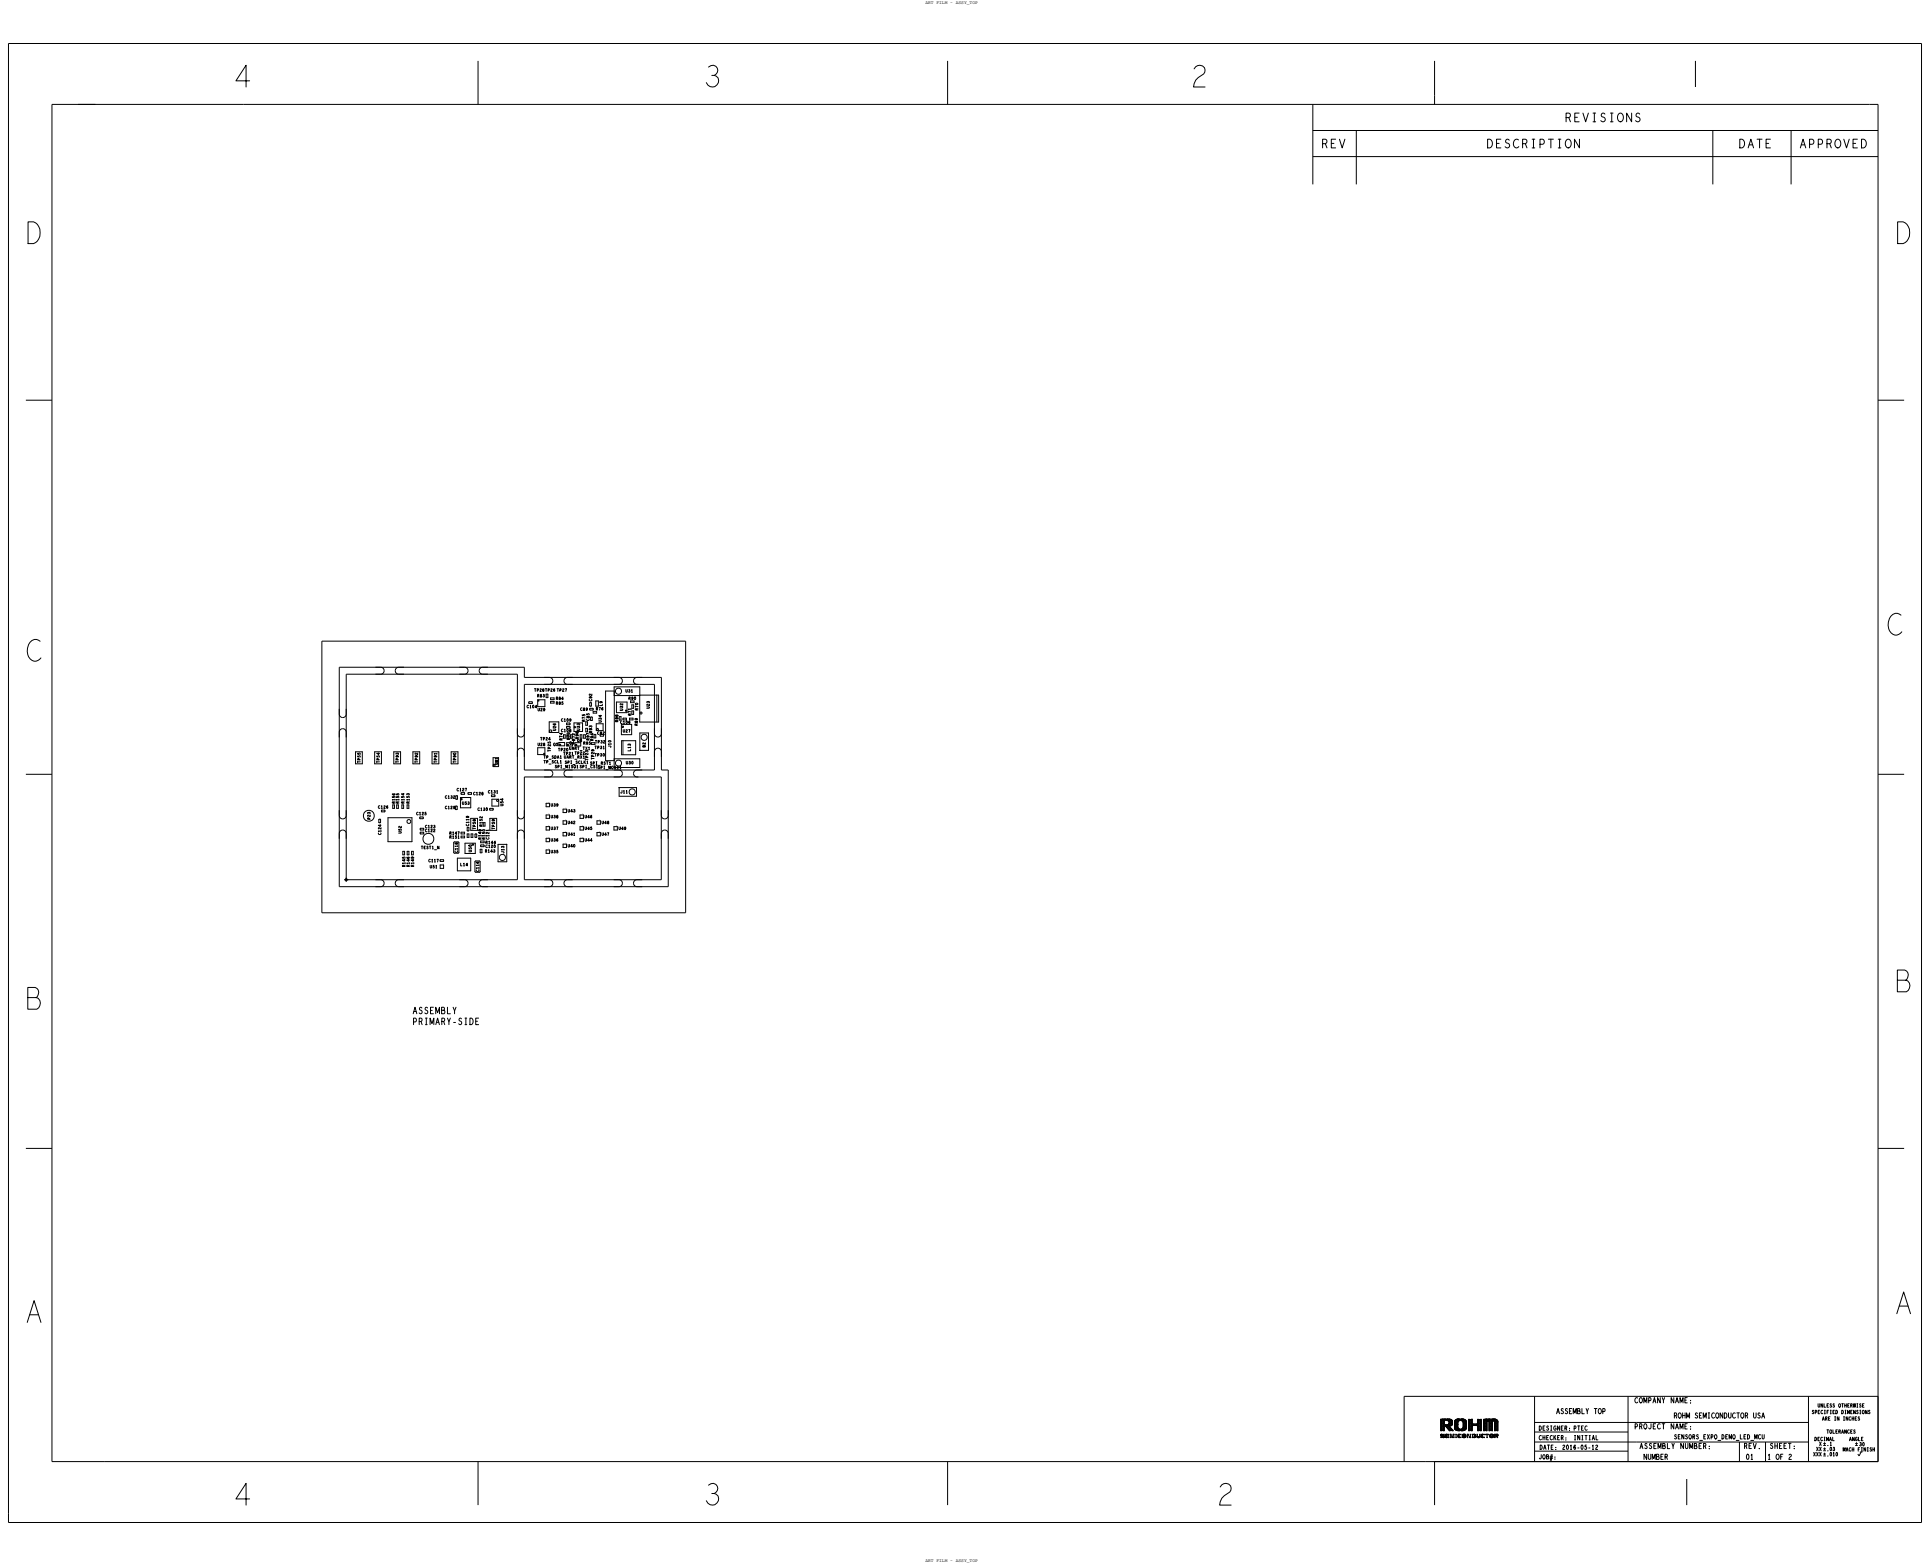
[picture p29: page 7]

REVISIONS

APPROVED

D

2

MACH FINISH; ANGLE; APPROVED; XXX; DECIMAL; TOLERANCES; SHEET:; DATE; REV.; ROHM; SEMICONDUCTOR USA; SENSORS_EXPO_DEMO_LED_MCU; PROJECT; NAME:; COMPANY NAME:; NUMBER; FAB NUMBER:; REVISIONS; INITIAL; PTEC; FAB DRAWING; JOB#:; DATE:; CHECKER:; DESIGNER:; REV; DESCRIPTION; applicable; specifications.; Customer; must be; advised; standards, and of; any specifications that cannot; met.; B. Producibility study - It; is the respondsibility of the; supplier; corrections; made or; recommendations to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

ART FILM - FAB

LAYER STACKING DETAIL

Ref. Layer | Layer # | Layer Type | Copper Weight (Oz) | Copper Thickness (Mils) | Material Type - Ply | Dielectric Thickness (Mils) | Finished Line (Mils) | Required Impedance (Ohms) | NOTE

NOTES:
1. Specifications.
A. Fabricate IAW IPC600, latest revision.

Solder Mask | | | | | | 0.5
Plating | | | | 1.3

1,2 | 1 | TOP | 0.5 | 0.65 | | | 40 | 50+/-10% | RF DETAIL A

2 | BOT | | 0.65

Total Overal Thickness:
Material Type : 370HR

6. Silkscreen
B. No silkscreen allowed on exposed lands.
C. Silkscreen must be a minimum of 3mm away form fiducial marks.
D. Minimum clearance between silkscreen legend and vias, pads, or holes
E. Silkscreen is allowed in via holes.

7. Electrical Test
A. All boards shall be 100% electrically tested for opens/short at 10 volts.
MIL-SPEC boards to be tested at 40 volts.
B. Apply test stamp in non-legend area on solder side of PCB.
C. Test is required on both sides of the board.

8. Cleanliness
A. Boards shall be free of fiber glass dust or any other foreign material.
B. Finished boards must conform to 0.01 MG/IN max NAcL ionic contamination
as meaxured by the omega meter 600SMD.

9. Packaging
There shall be a max of 25 units per package, individually wrapped,
and shipped in cardboard cratons with sufficient surrounding
material to prevend shipping damage.

DRILL CHART: TOP to BOTTOM
ALL UNITS ARE IN MILS

10. Bow and Twist
Bow and twist to be .007 IN/IN or .090 max according to IPC-A-600D.

12. Inside corners should be rounded-off

13. Changes to board geometries and apertures are not
allowed unless they are approved by customer.
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

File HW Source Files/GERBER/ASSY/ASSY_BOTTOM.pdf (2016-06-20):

## ART FILM - ASSY_BOTTOM


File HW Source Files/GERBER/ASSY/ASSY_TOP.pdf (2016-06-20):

## ART FILM - ASSY_TOP

D


REVISIONS

APPROVED

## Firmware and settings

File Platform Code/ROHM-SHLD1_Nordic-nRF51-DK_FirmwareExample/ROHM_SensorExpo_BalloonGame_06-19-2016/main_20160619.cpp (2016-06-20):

/* 
 * mbed Microcontroller Library
 * Copyright (c) 2006-2013 ARM Limited
 *
 * Licensed under the Apache License, Version 2.0 (the "License");
 * you may not use this file except in compliance with the License.
 * You may obtain a copy of the License at
 *
 *     http://www.apache.org/licenses/LICENSE-2.0
 *
 * Unless required by applicable law or agreed to in writing, software
 * distributed under the License is distributed on an "AS IS" BASIS,
 * WITHOUT WARRANTIES OR CONDITIONS OF ANY KIND, either express or implied.
 * See the License for the specific language governing permissions and
 * limitations under the License.
 */
 
 //BALLOON GAME!
 /*
 * 	Code Example for ROHM Sensor Expo Balloon Game
 * 
 *  Description: This Application interfaces ROHM's BM1383AGLV with Nordic's nRF51-DK
 *  This Code supports the following sensor devices:
 *      > BM1383AGLV Pressure Sensor
 *
 *  This Code allows the user to configure two known pressure distances and save pressure readings
 *	onto the application.  Then it will automatically extrapolate these values and allow the user to see
 *	the height of the board.  When connected to a balloon, greater heights can be achieved and the board
 *	will return the current height of the board.
 *   
 *  Additional information about the this Balloon Game can be found at the following link:
 *      asdfasdfasdf
 * 
 *  Last Upadtaed: 6/19/2016 
 *  Author: ROHM USDC
 *  Contact Information: engineering@rohmsemiconductor.com
 */

#define nRF52DevKit
#define Pressure            //BM1383, Barometric Pressure Sensor

#include "mbed.h"
#include "BLEDevice.h"
#include "UARTService.h"
#include "nrf_temp.h"
#include "I2C.h"
#include <string>

#define MAX_REPLY_LEN           (UARTService::BLE_UART_SERVICE_MAX_DATA_LEN)    //Actually equal to 20
#define SENSOR_READ_INTERVAL_S  (1.0F) 
#define ADV_INTERVAL_MS         (1000UL)
#define UART_BAUD_RATE          (19200UL)
#define DEVICE_NAME             ("ROHM DEMO  ") // This can be read AFTER connecting to the device.
#define SHORT_NAME              ("BALLOON1")    // Keep this short: max 8 chars if a 128bit UUID is also advertised.
#define DEBUG(...)              { m_serial_port.printf(__VA_ARGS__); }

// Function Prototypes
void PBTrigger();               //Interrupt function for PB4
void BTLE_DataWrittenHandler();

// Global Variables
BLEDevice   m_ble;
Serial      m_serial_port(p9, p11);  // TX pin, RX pin Original
//Serial      m_serial_port(p8, p10);  // TX pin, RX pin 
DigitalOut  m_cmd_led(LED1);
DigitalOut  m_error_led(LED2);
UARTService *m_uart_service_ptr;
DigitalIn   testButton(p20);
InterruptIn sw4Press(p20);
I2C         i2c(p30,p7);
bool        RepStart = true;
bool        NoRepStart = false;
int         i = 1;
unsigned char   printQue = 0;
string      ReceivedValue;
char        FormattedData[30];
uint8_t  	buf[MAX_REPLY_LEN];
uint32_t 	len = 0;

//Sensor Variables
#ifdef Pressure
int         Press_addr_w = 0xBA;
int         Press_addr_r = 0xBB;

char        PWR_ON[2] = {0x12, 0x01};
char        PWR_OFF[2] = {0x12, 0x00};
char        SLEEP_OFF[2] = {0x13, 0x01};
char        SLEEP_ON[2] = {0x13, 0x00};
char        Mode_Control[2] = {0x14, 0xCA};

char        Press_Content_ReadData[6];
char        Press_Addr_ReadData =0x1A;

int         BM1383_Temp_highByte;
int         BM1383_Temp_lowByte;
int         BM1383_Pres_highByte;
int         BM1383_Pres_lowByte;
int         BM1383_Pres_leastByte; 

short int   BM1383_Temp_Out;
float       BM1383_Temp_Conv_Out;
float       BM1383_Pres_Conv_Out;

float       BM1383_Var;
float       BM1383_Deci;

uint32_t    BM1383_TempPressure;


#endif

//Balloon Game Variables
float       BM1383_Pres_0Level;
float       BM1383_Pres_KnownLevel;
float       HeightBase = 0;
float       HeightKnown_Total = 68;
float       HeightKnown_Foot = 60;
float       HeightKnown_Inches = 8;
float       slope;
float       yInt;
float       pressureCurr;
float       HeightExtrapolated; //Assuming linear pressure curve
float       HeightExtrapolated_Foot = 60;
float       HeightExtrapolated_Inches = 8;


/**
 * This callback is used whenever a disconnection occurs.
 */
void disconnectionCallback(Gap::Handle_t handle, Gap::DisconnectionReason_t reason)
{
    switch (reason) {
    case Gap::REMOTE_USER_TERMINATED_CONNECTION:
        DEBUG("Disconnected (REMOTE_USER_TERMINATED_CONNECTION)\n\r");
        break;
    case Gap::LOCAL_HOST_TERMINATED_CONNECTION:
        DEBUG("Disconnected (LOCAL_HOST_TERMINATED_CONNECTION)\n\r");
        break;
    case Gap::CONN_INTERVAL_UNACCEPTABLE:
        DEBUG("Disconnected (CONN_INTERVAL_UNACCEPTABLE)\n\r");
        break;
    }

    DEBUG("Restarting the advertising process\n\r");
    m_ble.startAdvertising();
}

/**
 * This callback is used whenever the host writes data to one of our GATT characteristics.
 */
void dataWrittenCallback(const GattCharacteristicWriteCBParams *params)
{
    // Ensure that initialization is finished and the host has written to the TX characteristic.
    if ((m_uart_service_ptr != NULL) && (params->charHandle == m_uart_service_ptr->getTXCharacteristicHandle())) {
        int i;
        ReceivedValue.clear();
        for(i = 0; i < params->len; i++)
        {
            ReceivedValue += params->data[i];
        }
        printQue = 1;
    }
}

/**
 * This callback is used whenever a write to a GATT characteristic causes data to be sent to the host.
 */
void dataSentCallback(unsigned count)
{
    // NOTE: The count always seems to be 1 regardless of data.
    DEBUG("%d bytes sent to host\n\r", count);
}


/**
 * This callback is scheduled to be called periodically via a low-priority interrupt.
 */
void periodicCallback(void)
{
    //uint8_t  buf[MAX_REPLY_LEN];
    //uint32_t len = 0;
}

void error(ble_error_t err, uint32_t line)
{
    m_error_led = 1;
    DEBUG("Error %d on line number %d\n\r", err, line);
}

void PBTrigger()
{
    uint8_t  buf[MAX_REPLY_LEN];
    uint32_t len = 0;
    
    m_cmd_led = !m_cmd_led;
    
    if (m_ble.getGapState().connected) {
        len = snprintf((char*) buf, MAX_REPLY_LEN, "Button Pressed!");
        m_ble.updateCharacteristicValue(m_uart_service_ptr->getRXCharacteristicHandle(), buf, len);
    }
}

int main(void)
{
    ble_error_t err;
    Ticker      ticker;

    m_serial_port.baud(UART_BAUD_RATE);

    DEBUG("Initialising...\n\r");

    m_cmd_led      = 0;
    m_error_led    = 0;

    ticker.attach(periodicCallback, SENSOR_READ_INTERVAL_S);

    sw4Press.fall(&PBTrigger);

    #ifdef Pressure  //no Initialization because we keep in low power mode until we need to measure pressure
    //i2c.write(Press_addr_w, &PWR_OFF[0], 2, false);
    //i2c.write(Press_addr_w, &SLEEP_ON[0], 2, false);
    //i2c.write(Press_addr_w, &Mode_Control[0], 2, false);
    #endif

    //Start BTLE Initialization Section
    m_ble.init();
    m_ble.onDisconnection(disconnectionCallback);
    m_ble.onDataWritten(dataWrittenCallback);
    m_ble.onDataSent(dataSentCallback);

    // Set the TX power in dBm units.
    // Possible values (in decreasing order): 4, 0, -4, -8, -12, -16, -20.
    err = m_ble.setTxPower(4);
    if (BLE_ERROR_NONE != err) {
        error(err, __LINE__);
    }

    // Setup advertising (GAP stuff).
    err = m_ble.setDeviceName(DEVICE_NAME);
    if (BLE_ERROR_NONE != err) {
        error(err, __LINE__);
    }

    err = m_ble.accumulateAdvertisingPayload(GapAdvertisingData::BREDR_NOT_SUPPORTED);
    if (BLE_ERROR_NONE != err) {
        error(err, __LINE__);
    }

    m_ble.setAdvertisingType(GapAdvertisingParams::ADV_CONNECTABLE_UNDIRECTED);

    err = m_ble.accumulateAdvertisingPayload(GapAdvertisingData::SHORTENED_LOCAL_NAME,
                                                (const uint8_t *)SHORT_NAME,
                                                (sizeof(SHORT_NAME) - 1));
    if (BLE_ERROR_NONE != err) {
        error(err, __LINE__);
    }

    err = m_ble.accumulateAdvertisingPayload(GapAdvertisingData::COMPLETE_LIST_128BIT_SERVICE_IDS,
                                                (const uint8_t *)UARTServiceUUID_reversed,
                                                sizeof(UARTServiceUUID_reversed));
    if (BLE_ERROR_NONE != err) {
        error(err, __LINE__);
    }

    m_ble.setAdvertisingInterval(Gap::MSEC_TO_ADVERTISEMENT_DURATION_UNITS(ADV_INTERVAL_MS));
    m_ble.startAdvertising();

    // Create a UARTService object (GATT stuff).
    UARTService uartService(m_ble);
    m_uart_service_ptr = &uartService;

    while (true) {
        m_ble.waitForEvent();
        
        #ifdef Pressure
        /*
        //Read color Portion from the IC
        i2c.write(Press_addr_w, &Press_Addr_ReadData, 1, RepStart);
        i2c.read(Press_addr_r, &Press_Content_ReadData[0], 3, NoRepStart);
        
        BM1383_Var  = (Press_Content_ReadData[0]<<3) | (Press_Content_ReadData[1] >> 5);
        BM1383_Deci = ((Press_Content_ReadData[1] & 0x1f) << 6 | ((Press_Content_ReadData[2] >> 2)));
        BM1383_Deci = (float)BM1383_Deci* 0.00048828125;  //0.00048828125 = 2^-11
        BM1383_Pres_Conv_Out = (BM1383_Var + BM1383_Deci);   //question pending here...
        */
        #endif
        
        
        if(printQue)    //Handle Data Written Interrupt
        {
            BTLE_DataWrittenHandler();
            printQue = 0;
        }
    }
}

void BTLE_DataWrittenHandler(){    
    int i;
    if (ReceivedValue.length() == 1) {
        switch (ReceivedValue[0]) { 
            case 'F':
                len = snprintf((char*) buf, MAX_REPLY_LEN, "  Pres= %0.2f hPa", BM1383_Pres_Conv_Out);
                break;
            
            case 'r': //System Reset
                NVIC_SystemReset(); //Q. What is this? no break statement?
                                    //A. SoftReset... No need for break because this resets the program...
                break;
                
            default:
                len = snprintf((char*) buf, MAX_REPLY_LEN, "1b,ERROR");
                break;
        }
    }
    else if (ReceivedValue.length() > 1) {
        
        //BTLE Interface Code, Added 5/29/2016
        for(i = 0; i < 29; i++)
        {
            FormattedData[i] = '\0';
        }
        
        if(ReceivedValue.compare(0,4,"CAL0") == 0)
        {
			pressureCurr = 0;
			i2c.write(Press_addr_w, &PWR_ON[0], 2, false);
			i2c.write(Press_addr_w, &SLEEP_OFF[0], 2, false);
			i2c.write(Press_addr_w, &Mode_Control[0], 2, false);
			for(i = 0; i < 10; i++)
			{
				#ifdef Pressure
				wait_ms(200);
				i2c.write(Press_addr_w, &Press_Addr_ReadData, 1, RepStart);
				i2c.read(Press_addr_r, &Press_Content_ReadData[0], 3, NoRepStart);
				BM1383_TempPressure = (Press_Content_ReadData[0]<<14)|(Press_Content_ReadData[1]<<6)|(Press_Content_ReadData[2]);
				BM1383_Pres_Conv_Out = (float)BM1383_TempPressure / (float)2048;
				#endif
				pressureCurr += BM1383_Pres_Conv_Out;
			}
			i2c.write(Press_addr_w, &PWR_OFF[0], 2, false);
			i2c.write(Press_addr_w, &SLEEP_ON[0], 2, false);
			BM1383_Pres_0Level = pressureCurr/10;
			len = snprintf((char*) buf, MAX_REPLY_LEN, "BaseLvl=%.3f",BM1383_Pres_0Level);  
        }
        
        else if(ReceivedValue.compare(0,4,"CAL1") == 0)
        {
            pressureCurr = 0;
            i2c.write(Press_addr_w, &PWR_ON[0], 2, false);
            i2c.write(Press_addr_w, &SLEEP_OFF[0], 2, false);
            i2c.write(Press_addr_w, &Mode_Control[0], 2, false);
            for(i = 0; i < 10; i++)
            {
                #ifdef Pressure
                wait_ms(200);
				i2c.write(Press_addr_w, &Press_Addr_ReadData, 1, RepStart);
				i2c.read(Press_addr_r, &Press_Content_ReadData[0], 3, NoRepStart);
				BM1383_TempPressure = (Press_Content_ReadData[0]<<14)|(Press_Content_ReadData[1]<<6)|(Press_Content_ReadData[2]);
				BM1383_Pres_Conv_Out = (float)BM1383_TempPressure / (float)2048;
                #endif
                pressureCurr += BM1383_Pres_Conv_Out;
            }
            i2c.write(Press_addr_w, &PWR_OFF[0], 2, false);
            i2c.write(Press_addr_w, &SLEEP_ON[0], 2, false);
            BM1383_Pres_KnownLevel = pressureCurr/10;
            len = snprintf((char*) buf, MAX_REPLY_LEN, "KnownLv=%.3f",BM1383_Pres_KnownLevel);              
        }
        
        
        else if(ReceivedValue.compare(0,4,"HEI?") == 0)
        {
            HeightKnown_Total = HeightKnown_Foot + HeightKnown_Inches;
            slope = (HeightKnown_Total - HeightBase) / (BM1383_Pres_KnownLevel - BM1383_Pres_0Level);
            yInt = HeightBase - (slope * BM1383_Pres_0Level);
            pressureCurr = 0;
            i2c.write(Press_addr_w, &PWR_ON[0], 2, false);
            i2c.write(Press_addr_w, &SLEEP_OFF[0], 2, false);
            i2c.write(Press_addr_w, &Mode_Control[0], 2, false);
            for(i = 0; i < 10; i++)
            {
                #ifdef Pressure
                wait_ms(200);
				i2c.write(Press_addr_w, &Press_Addr_ReadData, 1, RepStart);
				i2c.read(Press_addr_r, &Press_Content_ReadData[0], 3, NoRepStart);
				BM1383_TempPressure = (Press_Content_ReadData[0]<<14)|(Press_Content_ReadData[1]<<6)|(Press_Content_ReadData[2]);
				BM1383_Pres_Conv_Out = (float)BM1383_TempPressure / (float)2048;
                #endif
                pressureCurr += BM1383_Pres_Conv_Out;
            }
            i2c.write(Press_addr_w, &PWR_OFF[0], 2, false);
            i2c.write(Press_addr_w, &SLEEP_ON[0], 2, false);
            pressureCurr = pressureCurr/10;
            
			HeightExtrapolated = ((pressureCurr * slope) + yInt)/12;
			//len = snprintf((char*) buf, MAX_REPLY_LEN, "Height=%f FT",HeightExtrapolated);
			//m_ble.updateCharacteristicValue(m_uart_service_ptr->getRXCharacteristicHandle(), buf, len);
			
			HeightExtrapolated_Foot = int(HeightExtrapolated);
			HeightExtrapolated_Inches = (HeightExtrapolated - HeightExtrapolated_Foot)* 12;
			len = snprintf((char*) buf, MAX_REPLY_LEN, "H=%.0fFT, %.0fIN",HeightExtrapolated_Foot,HeightExtrapolated_Inches);
        }
        
        else if(ReceivedValue.compare(0,2,"FT") == 0)
        {
            HeightKnown_Foot = (ReceivedValue[2]-48) * 12;  //Convert ASCII to INT, then Convert to Inches
            sprintf(FormattedData, "%2.0f", HeightKnown_Foot);
            len = snprintf((char*) buf, MAX_REPLY_LEN, "FT = %s inchs", FormattedData);
			wait_ms(200);
        }
        
        else if(ReceivedValue.compare(0,2,"IN") == 0)
        {
            if((ReceivedValue[3]>= 48) && (ReceivedValue[3]<=57)){
                HeightKnown_Inches = ((ReceivedValue[2]-48)*10) + (ReceivedValue[3]-48);    //Convert ASCII to INT, then Convert to Inches  
                
            }
            else{
                HeightKnown_Inches = (ReceivedValue[2]-48); //Convert ASCII to INT
            }
            sprintf(FormattedData, "%2.0f", HeightKnown_Inches);
            len = snprintf((char*) buf, MAX_REPLY_LEN, "IN = %s inchs", FormattedData);
			wait_ms(200);
        }
        
        else
        {
            len = snprintf((char*) buf, MAX_REPLY_LEN, "??? = %s", ReceivedValue.c_str());
            //m_ble.updateCharacteristicValue(m_uart_service_ptr->getRXCharacteristicHandle(), buf, len);
        }

    }
    else
    {
        len = snprintf((char*) buf, MAX_REPLY_LEN, "ERR:NUL");
    }
    m_ble.updateCharacteristicValue(m_uart_service_ptr->getRXCharacteristicHandle(), buf, len);
}
